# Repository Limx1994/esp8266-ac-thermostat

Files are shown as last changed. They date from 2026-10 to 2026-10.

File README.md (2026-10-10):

# 🌡️ 恒温养人控制器

> **空调负责干活，我负责让它懂事。**

一个基于 **ESP-12F** 的低功耗空调温控器。

它会自己测温、判断冷热、发送已经学会的遥控器指令。
不用 App，不连云端，配置完之后基本不用管。

## 能干什么

- 🌡️ DS18B20 自动测温
- 🎯 两组独立温控规则
- 📡 学习并发送空调红外指令
- 📱 手机连接 Wi-Fi 直接配置
- 💤 闲着就 light sleep，省点电
- 📈 温度变化越快，空调管得越勤

简单来说：

```text
太热了  → 发一个降温指令
太冷了  → 发一个升温指令
挺舒服  → 接着睡
```

## 怎么用

按 **S1** 开启热点，手机连接：

```text
空调智能温控
```

没有自动弹出页面时访问：

```text
http://192.168.4.1
```

设置温度 → 学习遥控器 → 测试发送 → 启用规则。

然后就可以把它扔在一边自己养人了。

## 实物图

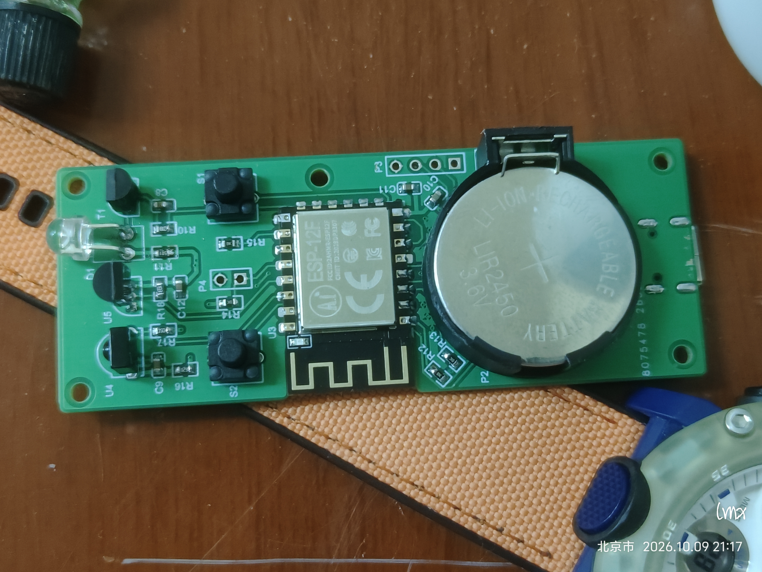
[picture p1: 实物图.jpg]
恒温养人控制器实物


## 配置页面

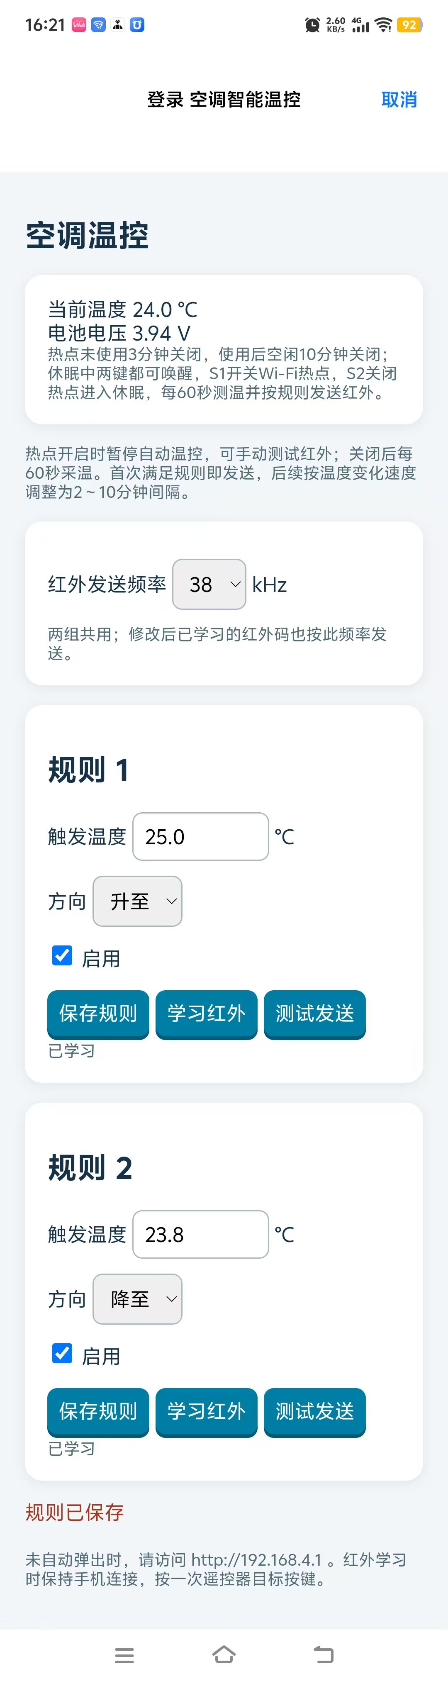
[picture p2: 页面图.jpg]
手机配置页面


## 它什么时候工作

| 状态 | 行为 |
| --- | --- |
| 热点开启 | 每 2 秒测温，方便配置，暂停自动红外 |
| 正常运行 | 每 60 秒测温并检查规则 |
| 空闲期间 | 自动 light sleep |
| 温度变化明显 | 自动发送间隔按趋势调整为 120～600 秒 |

S2 可以快速关闭热点，但**不会停止温控**。

## 构建

```powershell
Set-Location .\Sof
python build.py
python flash.py --port COM3 --dry-run
```

以上命令从本工作区根目录执行；构建和测试在 `Sof` 目录执行，Git 管理根目录为 `D:\空调温度`。默认分段烧录保留未覆盖的 NVS。

如果已经学好了遥控器，别随手整片擦 Flash，不然它会把自己刚学会的东西忘掉。

## 当前状态

本次发布版本（新增修复尚未重新实机验收）：

```text
0.5A · 2026-10-10
```

2026-10-09 用户确认：红外与 1-Wire 波形、空调响应、真实休眠/功耗、温度准确度、手机弹页、ADC 多电压点及 24 小时运行均已完成实机验证。该状态依据用户反馈；本次未补充具体测量数值、设备镜像哈希或测量记录。

0.5A 发布附件包含：

**网页温度/电压校准 / 学习按钮与 LED 反馈 / 分状态电压修正 / 红外与按键诊断**

保留 80 MHz、温度校准、60 秒采温和 120～600 秒趋势自动发送。本次纳入隐藏校准、学习状态反馈、电压单点修正及诊断日志；此前实机确认不直接替代新增修复镜像的验收，详情见 [本地发布](Sof/README.md#本地发布)。

既有文档记录的低电流读数（对应镜像、测量接点与积分条件未确认）：

```text
3.994 V · 10 µA
```

该读数不作为当前构建的功耗验收结果；仅凭 light sleep 配置不能确认整机电流或续航。当前软件检查与用户实机验证确认见 [本地发布](Sof/README.md#本地发布)。

## 文档导航

- [项目说明与软件检查](Sof/README.md)
- [硬件引脚与接线](Sof/ESP-12F硬件引脚与链路说明.md)
- [编译环境](Sof/ESP8266编译环境路径.md) · [烧录工具](Sof/tools/README.md)
- [功耗验收](Sof/README.md#功耗验收) · [温度校准](Sof/README.md#温度测量与校准)

本项目根目录为 `D:\空调温度`：`Sof` 为固件与测试，`Ad` 为硬件设计，`dxf-pdf` 为元件资料与 DXF 文件。

## 下载与许可

- [GitHub 仓库](https://github.com/Limx1994/esp8266-ac-thermostat)
- [0.5A Release](https://github.com/Limx1994/esp8266-ac-thermostat/releases/tag/v0.5A)：分段烧录包、完整镜像及 SHA256 校验清单。保留规则和红外编码时使用分段烧录；完整镜像会清除 NVS。
- 项目采用 [PolyForm Noncommercial 1.0.0](LICENSE)，附带第三方工具保留其原有许可。

---

**目标就一个：**

> 少折腾空调，多养养人。

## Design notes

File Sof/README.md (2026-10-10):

# 🌡️ 恒温养人控制器

> 空调负责干活，我负责让它懂事。

基于 ESP-12F 和 ESP8266 RTOS SDK 3.4 的空调温控器：DS18B20 测温、两组独立规则、红外学习与发送，手机连接本机热点配置；不依赖 App 或云端。热点关闭时每 60 秒采温，自动发送间隔随温度趋势在 120～600 秒调整，空闲时允许 light sleep。

## 文档导航

- [手机配置](#手机配置) · [运行行为](#运行行为) · [软件检查](#软件检查)
- [温度测量与校准](#温度测量与校准) · [电池电压](#电池电压) · [功耗验收](#功耗验收)
- [硬件引脚与接线](ESP-12F硬件引脚与链路说明.md) · [编译环境](ESP8266编译环境路径.md) · [烧录工具](tools/README.md)
- [本地发布与验证状态](#本地发布)

当前发布为 **0.5A（2026-10-10）**，标签 `v0.5A`。相对 0.1K，新增网页校准、学习状态反馈、分状态电压修正及诊断日志；新增校准 API 与 NVS 键，已有规则、红外码和载波数据保持兼容。验证状态见 [本地发布](#本地发布)。

Git 根目录为上层 `D:\空调温度`；本目录 `Sof` 仍是固件构建与测试入口。上层 `Ad` 保存硬件设计，`dxf-pdf` 保存元件资料和 DXF 文件。原有历史保留，迁移前版本的路径以当时树结构为准。

## 手机配置

1. 按 S1 开启热点，连接开放 Wi-Fi `空调智能温控`。未自动弹页时访问 `http://192.168.4.1`。
2. 设置两组规则的触发温度（−10～50 °C）、升温或降温方向，保存规则。
3. 点击对应组的“学习红外”，在 15 秒内按一次遥控器目标按键；学习成功后先用“测试发送”验证，再启用并保存规则。
4. 两组共用红外发送频率（36/38/40 kHz，默认 38 kHz）。修改后保存到 NVS，并影响所有已学习编码的后续发送。HS0038B 不能测出遥控器载波频率，需用目标空调验证兼容性。

学习码写入并提交 NVS 后，会读回逐字节核对；核对失败不显示学习成功，当前内存中的旧编码保留，但已提交的 Flash 内容需重新学习确认。学习成功、开机加载及发送完成日志均记录 `code=` 内容校验值，同一组可据此对比重启或休眠前后是否变化。启动时缺失或无效的 NVS 编码会明确记录。默认 `python flash.py` 分段烧录不覆盖 NVS；整片烧录 `full_flash.bin` 或擦除 Flash 会清除保存的数据。编码仍在但空调无响应时，还需核对学习波形及实际发射。

点击学习后，该组按钮立即显示“学习中···”，等待及采集期间保持；两组学习按钮暂时禁用，成功、超时或其他失败后恢复“学习红外”。页面底部继续保留详细结果；若页面重新打开时已有学习在进行，接口未提供学习槽位，两组按钮均显示“学习中···”并禁用，结束后恢复。

## 温度测量与校准

当前接法按用户确认：外置裸 DS18B20、VDD/DQ/GND 三线供电、DQ 使用 4.7 kΩ 上拉、引线不超过 1 米。相邻显示变化 0.1～0.2 ℃本身不能证明绝对误差超标。目标是在 18～30 ℃内实测误差不超过 ±0.5 ℃，±0.3 ℃仅作为改善目标；[DS18B20 官方数据手册](https://www.analog.com/media/en/technical-documentation/data-sheets/ds18b20.pdf)给出的 −10～85 ℃精度为 ±0.5 ℃，12 位分辨率为 0.0625 ℃。尚无参考温度计对照数据，默认偏移为 0，不加滤波或控制回差。

先固定探头在通风处，避开主板、电源、充电电路、日晒及空调直接出风，避免手持；检查接点与探头端供电，若探头端没有去耦，在 VDD/GND 附近增加 100 nF 电容。参考温度计的已知准确度须优于 ±0.2 ℃，两探头靠近但不接触，保持相同高度和气流，裸传感器不直接浸水。热平衡至少 15 分钟且参考读数稳定后，连续记录 10 分钟配对数据；分别对照热点开启、关闭及 USB 充电状态，记录平均偏差、波动范围和读取失败次数。建议记录列为时间、参考温度、`raw16`、`temperature10`、AP/充电状态和错误；`raw16 / 16` 为未校准摄氏温度。现场安装、去耦、参考仪器及这些测量均尚未核验。

若误差达标，保留零偏移。若偏差随热点或充电状态明显变化，先解决安装受热，不能用固定偏移补偿；只有热平衡后的稳定偏差才做单点校准。在约 25 ℃求 `偏移℃ = 平均参考温度 − 平均原始温度`，四舍五入为 0.1 ℃的整数填入固件目录生成配置 `sdkconfig` 的 `CONFIG_APP_TEMP_OFFSET10`，再执行 `python build.py`。例如参考为 25.0 ℃、原始平均为 25.3 ℃时设为 `-3`，即减 0.3 ℃。范围为 −50～50（±5.0 ℃），不是允许误差；明显大偏差应先排错。`sdkconfig.defaults` 默认值为 0，不覆盖已有 `sdkconfig`，构建后须核对 `build\auto\config\sdkconfig.h` 的实际值。编译偏移不写入 NVS；0.5A 提供网页追加偏移，见 [网页隐藏校准](#网页隐藏校准)。

固件在原始 1/16 ℃读数上应用偏移后，仅做一次四舍五入到 0.1 ℃；显示与规则判断共享同一结果。每次转换前读取并 CRC 校验 scratchpad 的分辨率，只有低于 12 位时才保留 TH/TL 并修正 RAM，读回确认后启动转换，不写传感器 EEPROM。核验/读回失败上报错误并阻止本次控制；结束读取仍保留 CRC/设备未找到最多三次重读、85 ℃默认值拒绝及 GPIO 清理错误上报，转换后分辨率变回低位也拒绝该读数。日志 `raw16`、`resolution=12`、`offset10`、`temperature10` 用于追踪原始与校准结果；这些日志表示有效 scratchpad 已解码，最终成功还要求总线清理成功。静默 UART 配置下不输出运行诊断。

校准后在约 18 ℃、30 ℃独立复核，并在三个温点分别检查热点开启/关闭、充电状态及休眠恢复后的读数与规则触发。仅在参考稳定的区间评估，配对温度误差须不超过 ±0.5 ℃；记录失败数量和原因，不将失败或缺失读数计作成功。若多温点仍不能达标，停止追加补偿，换用可追溯来源的 DS18B20 后重新核验。软件测试不能代替此项实机精度验收。

## 电池电压

电压随测温采集，使用 `adc_read` 单次读取，按当前板实测参考做单点增益校准；返回值超出 0～1023 时报错，不额外开启 RF。页面每 2 秒刷新、显示两位小数，刷新不增加采样频率。日志的 `measured` 仍保留按 330 kΩ / 82 kΩ 名义分压换算的未校准值。

boot 原 ADC 参考为 843；2026-10-10 用户确认外部模拟电池的稳定 3.795 V 为基准，冷启动 ADC746，网页比例为 `3794/3790`。扣除网页比例后将 boot ADC 参考改为 786，基准换算为 `battery_mV = round(adc × 3994 / 786)`，ADC746 基准3791 mV、追加后3795 mV。AP 保留同步样本 `adc=702 → 3595 mV`，换算为 `round(adc × 3595 / 702)`。sleep 原参考为 909.5；同一 3.795 V 基准下连续 11 次非 AP 采样有 10 次 ADC811、1 次 ADC812，网页比例为 `3794/3790`。扣除网页比例后拟合 sleep，将双倍 ADC 参考从 1819 改为 1709，基准换算为 `round(adc × 3994 × 2 / 1709)`；随后仍追加网页比例，ADC811 得到 3795 mV，ADC812 得到 3799 mV。所有分支使用整数运算保留 ADC 变化，取代旧 101/111 临时补偿。AP 关闭且经历允许自动休眠的等待后使用 sleep 参考，其余使用 boot 参考；该状态标记不证明实际已经入睡。

日志保留 `adc`、`measured`、`compensated` 及 `cal=boot/ap/sleep`；`measured` 为原名义换算值，不是万用表实测值。`compensated=1` 只表示选用 sleep 校准分支，所有分支都做校准。页面和低电量判断使用分状态基准再乘网页比例后的电压：低于 3.5 V 提示，达到 3.5 V 隐藏；读取失败显示错误，不影响温控。boot、sleep 基准根据本板稳定 3.795 V 样本修正，AP 保留 3.595 V 样本；其他板、160 MHz 或其他电压点应重新实测。ADC 状态差异根因及全电压范围精度未确认，3.5 V 边界仍需独立核验。

电压诊断另记录 `base_mv`（分状态换算结果）、`ratio=参考mV/基准mV`（网页追加比例）及最终 `battery`，这些数值来自同一次状态锁快照。`phase=ap/cold-start/after-ap` 区分热点采样、未开启过热点的采样和热点关闭后的采样；该阶段与 `cal` 分支分别记录，不能把 `cold-start` 阶段等同于 `cal=boot`。`off_sample` 为当前非 AP 阶段采样序号（含失败），开启热点清零；`off_ms` 从主循环检测热点关闭后起算，到 ADC 采样时刻为止，冷启动和 AP 时为 0。这些字段不证明真实入睡或唤醒原因，不改变采样周期、ADC 调用次数及原换算系数。

2026-10-10 旧 sleep 系数的对照日志：网页比例 `3794/3790`，AP ADC740～741 显示 3.794～3.799 V；非 AP ADC811 的 sleep 基准为 3561 mV，追加后为 3565 mV，用户同步实测为 3.795 V。随后 11 次稳定样本确认持续偏差，按上述方法单独修正 sleep。实机仍须保持电池端电压稳定，核对关闭 AP 后首次及随后至少 3 轮采样，并补充冷启动、第二电压点及 3.5 V 边界。

### 网页隐藏校准

0.5A 支持在同一标题上 3 秒内点击 5 次：规则 1 打开温度校正，规则 2 打开电池电压校正。两个标题独立计数，超时或关闭弹框清零。弹框显示当前读数；输入参考仪表实测值后保存，取消不修改配置。保存期间禁止重复提交；失败保留输入并显示原因，成功关闭并刷新读数。

弹框宽度包含内边距，最大 340 px，内容超出高度时内部滚动；打开时不自动聚焦或弹出键盘。弹出后的前 800 ms 忽略保存、取消，避免五次点击后的惯性点击误提交或立即关闭；之后点击输入框进行编辑并正常保存/取消。

温度参考范围 −10～50 ℃，输入精度 0.1 ℃；追加偏移为 `参考温度 − 未经网页校准的温度`，限制 ±5.0 ℃。保留原编译偏移，网页追加偏移参与页面、温控和 thermostat 日志；sensor 的 `temperature10` 诊断仍表示应用编译偏移后的基准。成功校准清空趋势和规则判断状态，保留成功发送计时，避免校准跳变被当作温度趋势。

电压参考范围 2.5～4.5 V，输入精度 0.001 V；比例为 `参考电压 / 当前 AP 基准电压`，限制 0.5～1.5。boot/AP/sleep 各自按分状态 ADC 系数换算，再统一乘网页比例并整数四舍五入，参与显示、thermostat 日志及低电量判断。网页修改人工目标后，保存的新比例同时用于三个状态，并在重启时加载；boot 不固定输出 3.795 V。非 AP 不使用 AP 的 ADC 参考。两类重复校准均替换追加参数，不累加或累乘。

`POST /api/calibration` 接受温度 `{"type":"temperature","reference10":255}` 或电压 `{"type":"battery","referenceMv":3595}`。服务端使用最近一次有效基准样本，超过 5 秒、读取失败或电压基准为零时拒绝；电压要求 AP 样本。参数或幅度越界返回 400，样本不可用返回 409，存储失败返回 500，成功返回 200。

追加参数分别写入 `ac` NVS 的 `temp_adj` 和 `bat_adj`，提交成功才更新内存及当前读数；存储失败保留原参数。重启加载，缺失使用零偏移和单位比例；损坏或读取失败明确报错并按现有启动错误机制终止。已有规则、红外编码及载波 NVS 格式保持兼容。单点校准不能证明全范围准确，需核对温控判断、相同电池电压下 AP/非 AP/休眠后的读数。

## 运行行为

| 状态 | 测温与控制 | 指示灯 |
| --- | --- | --- |
| 开机、热点关闭 | 开机立即测温，之后每 60 秒测温并检查规则 | 熄灭 |
| 热点开启 | 每 2 秒测温，暂停自动发送与趋势计算 | 每秒亮 500 ms |
| 红外学习 | 等待信号和采集期间保持唤醒，结束后恢复热点指示 | 常亮 |
| S2 休眠温控 | 关闭热点，每 60 秒测温并检查规则，间隔允许自动 light sleep | 熄灭 |

S1 可提前关闭热点；红外学习或发送期间将关闭请求延后到红外空闲，再按 S1 可取消待处理请求。休眠中 S1、S2 均通过 GPIO 唤醒：S1 开关 Wi-Fi 热点，S2 快速关闭热点并返回休眠温控。S2 关闭热点后继续每 60 秒采温和按规则发送红外；重复按 S2 不暂停温控、不清空规则状态，S1 可重新开启热点。红外忙碌时，S2 关闭请求延后到空闲；关闭失败会上报错误，温控继续，但不能保证进入休眠。DS18B20 转换期间的按键需等待约 750 ms 加一个 FreeRTOS tick 后处理；长按只产生一次操作。热点关闭失败会记录错误，保留状态供再次操作。

热点开启后，未访问控制页或操作配置 API 时，3 分钟后关闭；使用后从最后一次上述操作起空闲 10 分钟关闭，自动回到休眠温控。状态轮询、系统探测及后台请求不延长期限；红外忙碌时延后关闭。

热点关闭时，每次有效采温判断启用的规则：升温方向在温度大于等于阈值时满足，降温方向在温度小于等于阈值时满足。首次满足立即发送，不要求跨越阈值，也不使用回差。已发送的组须达到当前动态间隔后，在下一次有效采样发送；两组共用间隔、独立记录成功发送时间。

趋势使用最近五点两两斜率的中位数，另取最近两段同方向变化的较小速度作为快速路径，两者取较大绝对速度。目标间隔对应约 1 ℃变化，限制在 120～600 秒；缩短立即生效，延长每次最多增加 60 秒。初始或重置间隔为 600 秒，速度为零时目标为 600 秒。热点开启、测温失败或采样间隔超过 120 秒重置趋势；不会清空各组成功发送计时。日志 `trend` 记录点数、速度、目标与实际间隔，`automatic send` 记录组号和结果。

S2、正常休眠、规则或编码变更不清空成功发送计时。条件不满足、规则禁用、未学习编码或正在学习时不自动发送；测温失败阻止本次发送，恢复后重新判断。发送失败不更新成功计时，后续有效采样可重试。网页测试发送不受自动间隔限制。60 秒采样可能漏掉短暂越界，也可能使实际发送晚于目标间隔。

## 红外与诊断

GPIO5 接收输入启用内部上拉，初始化时关闭边沿中断；仅安装学习回调后开启双边沿，学习结束、超时或出错时先在临界区关闭硬件中断并清除待处理状态，再移除回调，之后才处理编码和 NVS。回调移除失败会明确记录错误，不显示学习成功，硬件中断仍保持关闭。硬件说明记录 GPIO5 已有 11 kΩ 外部上拉，不能仅凭拆除接收管就认定引脚悬空；非学习期间关闭中断用于避免无用的边沿处理，节电效果待实测。

红外学习按 10 μs 单位保存完整解调时序，最多 960 段、总时长不超过 750 ms。捕获使用 `esp_timer_get_time()` 计时，保存尾部空闲段；超限、无效波形或保存失败均报错，保留旧编码。学习流程及 NVS 格式保持兼容，无需重新学习；AP 开启时使用 I2S WS + FRC1，AP 关闭时使用 GPIO14 软件载波。清理失败会报错并阻止自动休眠。

DS18B20 的复位和逐位读写使用 RTOS 临界区保护。关键时隙函数放在 IRAM，直接读写 GPIO4 寄存器，按构建配置（当前固定 80 MHz）的 CPU 计数器等待各边沿和采样点，避免临界区内的 GPIO API 和 Flash 延时函数带来缓存等待。读位在起始后约 13 μs 采样；计数器差值支持回绕。临界区不覆盖 750 ms 转换等待，也不在其中输出日志；CRC 失败仍报错，不采用旧温度代替有效读数。主机模拟与链接检查不能代替实际 1-Wire 波形和休眠后测温验证。

发送取得忙碌标志和独立休眠锁后，根据 `portal_is_on()` 固定本次路径，日志标记 `backend=i2s/software`。发送前输出编码校验值、恢复 GPIO14 推挽输出并等待 UART 发完；帧内不输出诊断日志。AP 开启路径保留原有 I2S WS + FRC1，不使用 DMA，也不通过 `GPIO_IN` 回读作为发送成功门槛。

AP 开启路径通过 SDK 已链接的 `rom_i2c_readReg_Mask` / `rom_i2c_writeReg_Mask` 保存、使能并读回音频时钟位，仅操作 block `0x67`、host `4`、register `4` 的 bit `7`；定义依据为 [ESP8266 Arduino 的 I2S_CLK_ENABLE](https://github.com/esp8266/Arduino/blob/master/cores/esp8266/esp8266_peri.h)。`audio clock: before=... enabled=...` 记录保存值及使能后读回值；使能验证失败明确报错。停止 I2S 后恢复原值；停止或恢复失败保留原值及休眠锁，后续重试成功再释放。已有未清理的 I2S 状态不能通过软件路径绕过。

AP 关闭路径直接跳过音频时钟读写、I2S 配置和启动，不先尝试使能再回退，也不调用 `phy_open_rf()` 或开启热点。先停止 FRC1、将 GPIO14 拉低，再在整帧 RTOS 临界区内按保存的包络输出软件载波。关键函数及调用链在 IRAM，直接写 GPIO 寄存器，按构建配置（当前固定 80 MHz）的 `ccount` 累计截止时间计时；周期为 `round(cpu_mhz * 1000000 / frequency_hz)`，高电平占约半周期，支持 36/38/40 kHz。末尾不完整载波周期在包络截止时截断。保留现有段长和总长范围，最长 750 ms 内普通 RTOS 中断及按键处理会延后；NMI 看门狗保持启用。

软件发送记录 `late_cycles`，为边沿或包络结束相对截止时间的最大迟到 CPU 周期数；当前 80 周期为 1 μs。超过 400 周期（5 μs）时立即拉低输出并返回 `ESP_ERR_TIMEOUT`，不计入成功发送间隔，后续有效采样可重试。5 μs 是软件故障检测阈值，不代表实测精度。发送结束或失败均退出临界区、拉低输出并停止 FRC1；只有整帧完成且清理成功才返回 `ESP_OK`。FRC1 ISR 在软件路径不操作包络或 GPIO mux。

历史实机日志将 AP 关闭后的失败定位到 `stage=clock-enable`：音频时钟置位后读回仍为 0，实际包络为 `segments=0/140`。底层时钟为何不能恢复尚未确认；软件路径绕过该阻断，用户已于 2026-10-06 确认此前 160 MHz 软件载波实机验收成功；已有 80 MHz 基线的 AP/休眠红外正常反馈，最新实机验证确认见 [本地发布](#本地发布)。两条路径均保留 `esp_sleep_lock()` / `esp_sleep_unlock()` 独立保护，清理失败保留锁，后续清理成功释放，避免重复加锁；两条路径均不因发送改变 RF 状态，自动成功发送按每组 120～600 秒动态间隔计时。

最近一次发送的返回值、路径、阶段、包络完成段数、最大迟到周期数及 I2S 时钟状态留在 RAM，下次采样前通过 `previous send` / `previous clock` 输出。`seq` 为发送序号；多次发送只保留最近一次，断电或复位不保留。软件路径输出 `previous clock: not used`，时钟字段内部为 `-1`，不冒充使能或恢复成功。`stage=envelope result=ESP_ERR_TIMEOUT` 在软件路径表示时序迟到，在 I2S 路径表示等待包络完成超时；清理错误另列。`carrier configured` 和 `software carrier configured` 中的 `calculated` 均为配置计算频率，不是实测频率。`send complete` 或 `ESP_OK segments=140/140` 只代表发送流程及清理完成，不能证明空调已接收。

主机测试分别以 80/160 MHz 编译，覆盖启动频率不匹配、实际源码的 GPIO 边沿、三种载波配置、整帧包络、750 ms 边界、计数器回绕、模拟 NMI 延迟、清理失败重试、NVS 编码保存及两组动态间隔；模拟结果和链接检查不能证明硬件输出准确。实机验收以空调实际响应为准，用户已确认此前 160 MHz 软件载波验收成功；80 MHz 基线也已收到 AP/休眠红外正常反馈；用户已确认当前红外波形和空调响应通过实机验证；所有遥控协议及三种载波配置的完整兼容性未逐项声明。

## 休眠与供电

正常测温间隔和 S2 休眠温控使用 SDK 自动 light sleep，定时唤醒采温及发送红外，完成后继续休眠。热点关闭期间通过 SDK 的 `phy_close_rf()` 关闭 RF，包括测温和红外处理时；开启热点前通过 `phy_open_rf()` 恢复 RF。热点开启、1-Wire 通信、红外学习或发送期间保持 CPU 唤醒。每次测温先检测 DS18B20 供电：独立供电、热点关闭且红外空闲时，GPIO4 切为输入，由板上 4.7 kΩ 上拉维持 DQ 高电平，转换等待允许休眠；读取前关闭自动休眠并恢复开漏输出。RF 开关流程已纳入主机测试，用户已确认真实休眠/功耗完成实机验证；具体电流及 RF 测量记录未在本次补充。

转换等待保持 750 ms，并额外等待一个 tick 防止提前读取；转换前核验并确保 12 位分辨率。寄生供电时输出一次警告，保持唤醒等待，不提供强上拉支持。主任务等待下一次采样期限，按键通知可提前唤醒；单次上限按 CPU 频率保留 32 位计时余量，80 MHz 下单次最多约 52.68 秒，160 MHz 回退时最多约 25.84 秒；60 秒采温等待会分段，分段不额外采温。实际睡眠时长仍由 SDK 调度器决定。休眠配置失败后尝试关闭自动休眠并继续温控；若已启用的休眠无法关闭，则中止运行并报错。

本项目使用 LIR2450 锂电池，容量约 120 mAh。电池端功耗测量、按键和连续运行验收见 [功耗验收](#功耗验收)。当前节电比例与续航尚未确认。

休眠诊断使用现有链接包装机制，在 RAM 中累加，随测温采样、间隔至少 30 秒输出两行 `sleep_trace`；不增加任务、定时器、RTC 校准或休眠锁。`auto` 是 SDK 自动入口次数，`auto_no_hw` 是入口返回前没有低层尝试的次数；`hw` 是低层尝试，`hw_ok` 仅表示原函数返回 0，`hw_reject` 是硬件报告拒绝的次数。这些次数及 `bad_cal`、`zero_rtc` 均为本窗口增量；窗口可能跨越未完成的入口，不能要求计数严格相加。

`rtc_call_est_ms` 是本窗口未报告拒绝的低层调用前后 RTC 区间估算，使用本次 SDK 校准值，包含进入/退出开销，不使用尚未补偿的系统时间计量睡眠。`bad_cal` 和 `zero_rtc` 分别表示因缺少有效校准或 RTC 未推进而跳过估算的次数；`max_est_ms_total` 为启动以来单次最大估算值，`last_reject` 为最近一次非零返回值。`reasons=unavailable` 表示不能区分 SDK 内部锁、模式、GPIO 和期限等提前退出原因。统计及其与 `window_ms` 的比值不能作为精确睡眠时长或占比；诊断日志本身也有耗电，电流对比须保持相同诊断配置。操作步骤见 [休眠统计验收](#休眠统计验收)。

当前构建开关定义在 `main\Kconfig.projbuild`，默认值在 `sdkconfig.defaults`；已有 `sdkconfig` 不会自动同步。改变开关后须重新构建并核对生成配置。

| 配置 | 当前默认值 | 行为与限制 |
| --- | --- | --- |
| `CONFIG_APP_PAUSE_NOISE_TIMER` | 开启 | RF 关闭后取消 SDK 噪声定时器并阻止重登记，AP 启动前恢复；仅实际软件定时器队列为空时忽略旧 FRC2 alarm，保留计数及唤醒时钟补偿 |
| `CONFIG_APP_PAUSE_NETWORK_TIMERS` | 开启 | AP 关闭后在 TCP/IP 线程同步暂停周期及按需 TCP 定时器，开启前恢复；保留一次性超时，暂停期间网络状态不按周期老化 |
| `CONFIG_APP_DISABLE_DHCP_CLIENT_TIMERS` | 开启 | 构建时移除 DHCP 客户端 fine/coarse 周期项，保留 DHCP 服务端；仅适用于当前 AP 用途，增加 STA 前须关闭并重验 |
| `CONFIG_APP_QUIET_UART` | 关闭 | 开启时初始化后关闭运行日志并将 GPIO1 切为输入；排错需关闭并重新构建 |
| `CONFIG_APP_IDLE_BOOT_PINS` | 开启 | 初始化后释放 GPIO0/15 为无内部上下拉输入，依赖板上外部启动电阻 |
| `CONFIG_APP_SENSOR_IDLE_INPUT` | 开启 | GPIO4 初始化、转换启动失败或读温完成后释放为输入，下一次事务恢复开漏 |
| `CONFIG_APP_TEMP_OFFSET10` | 0 | 在原始温度舍入前应用 0.1 ℃整数偏移，未取得稳定偏差时保持 0 |

定时器恢复/停止失败明确返回错误；网络停止失败时不暂停其定时器。诊断随原采样汇总，不新建任务或周期定时器：最近最多 4 次低层调用记录 RTOS/FRC2 期限与 RTC 区间，`frc2_pending` 表示实际 SDK 软件定时器队列是否非空；最多 16 个 `wait_task` 组合只记录大于 0 且不超过 1 秒的请求等待，零等待、长/无限等待及溢出分别计入 `filtered_zero`、`filtered_long_or_infinite`、`dropped_full`。这些记录不是实际超时或真实唤醒原因，调用地址必须用同一镜像 ELF 解码。`noise_timer` 与 `network timers paused/resumed` 日志用于检查暂停、恢复和剩余队列，具体步骤见 [功耗验收](#功耗验收)。

## 构建与烧录

在 `Sof` 固件目录使用 PowerShell；从项目根目录先执行 `Set-Location .\Sof`：

```powershell
python build.py
python flash.py --port COM3 --dry-run
```

构建脚本扫描 `main` 的 C 源文件并更新组件源文件列表，临时映射空闲的 `Z:`，使用 CMake 和 Ninja `-j 12`，产物位于 `build\auto\`。SDK 可通过 `IDF_PATH` 覆盖，工具路径见 [编译环境说明](ESP8266编译环境路径.md)。从其他目录运行时使用脚本的绝对路径。

`sdkconfig.defaults` 设置 CPU 固定 80 MHz、晶振与 Flash 各 26 MHz、`CONFIG_PM_ENABLE=y`、HTTP 请求头上限 2048 字节和 URI 上限 1024 字节。已有 `sdkconfig` 不会被 defaults 覆盖，须同步选择 80 MHz；实际参数以构建生成的 `sdkconfig.h` 和 `flasher_args.json` 为准。

项目 `components\esp_http_server` 覆盖 SDK 的路由、解析和 socket 错误处理，其余实现、头文件及 Kconfig 继续使用指定 SDK。末尾 `*` 匹配剩余路径，`/generate_204_*` 探测重定向至控制页，`/mmtls/*` 的 GET/POST 返回 404。不支持的协议起始字节直接关闭连接，以 INFO 记录原因；HTTP 解析失败返回错误并关闭连接，收发错误保留真实 `errno`。

dry-run 只检查布局，不打开串口、不写 Flash。实际接线与烧录命令见 [工具说明](tools/README.md)；分段偏移以本次构建为准。完整 4 MB 镜像的未使用区域填 `0xFF`，整片写入会清除 NVS；保留规则和编码时使用分段烧录。

## 软件检查

以下命令逐条执行，成功后再执行下一条：

```powershell
New-Item -ItemType Directory -Force build_ascii | Out-Null
& "D:\APPS\Espressif\tools\ninja\1.9.0\ninja.exe" -f tests\build.ninja -j 12
.\build_ascii\rules_test.exe
python tests\test_power.py
python tests\test_portal.py
python -m unittest discover -s tests -p test_flash_port.py
python -m unittest discover -s tests -p test_tools.py
node --check tests\check_page.js
node tests\check_page.js
python flash.py --port COM3 --dry-run
git diff --check
```

规则测试检查阈值、等号、首次满足、重复满足及禁用规则；功耗主机测试检查实际控制、传感器和红外代码的流程与错误处理；HTTP 主机测试检查路由、解析、请求体清理、超时与 socket 错误；串口测试检查自动选择条件；页面检查验证六个 API 路径、2 秒刷新、共享载波保存、隐藏校准及温度/电池错误显示。

主机测试使用现有 GCC 和 SDK mocks，C 编译启用 `-Wall -Wextra -Werror`，产物保存在 `build_ascii\`。功耗测试需要本次构建生成的 SDK 副本，须先运行 `python build.py`。测试覆盖 80/160 MHz、基线/测量配置及温度偏移，另检查实际 SDK 定时器表、暂停/恢复与失败回退。这些测试不验证实际睡眠、电流、红外波形或手机弹页；最新结果与硬件待验项见 [本地发布](#本地发布)。

### 覆盖统计

以下运行器及扩展测试纳入 0.1J 源码，0.1I 发布不包含它们。先执行 `python build.py`，再从 `Sof` 目录运行以下命令。coverage 已安装在项目内忽略目录时可跳过安装命令，不增加固件依赖：

```powershell
python -m pip install --target build\coverage\packages coverage==7.16.2
python tests\run_coverage.py *> build\coverage\run.log
```

运行器使用 GCC/gcov、Python coverage 和 Node.js V8，复用现有主机测试；每个 C 编译组合保存独立计数。报告位于 `build\coverage\report.md`，关键路径矩阵、未命中源码行/分支、原始统计和产物哈希保存在同目录。C 行/函数按源码位置合并，分支按各变体分别计数；另提供相同 gcov 图结构的汇总，原始分母和缺口保留，不代替逐配置验收。V8 块范围不能等同于 GCC 分支。未插桩源码明确列出，测试、第三方 SDK 和附带工具不纳入业务覆盖率。

0.1J 的 HTTP 修复包括拒绝非 HTTP/1.x、零字节发送报错、接收缓存截断复制和 URI 分配失败槽位清理；相关覆盖统计适用于本次验证源码，不代表 0.1I 发布镜像。

所有可执行检查通过仍不代表全覆盖：存在覆盖缺口时运行器返回 `1`，报告标记“未完成”。代码中的保护分支不自动豁免；当前主机结果不证明实机波形、功耗、精度或真实并发。烧录动作由 mock 或 dry-run 验证，不写入设备。

## 清理

在 Windows PowerShell 5.1 中执行 `.\clean.ps1` 直接清理，使用 `.\clean.ps1 -WhatIf` 预览、不删除文件。原有 `-Apply` 参数保持兼容，显式传入 `-Apply:$false` 也可仅预览。脚本可通过绝对路径从其他目录调用。

清理范围为 `build\s1_checkpoint`、`build\s1_build.log`、整个 `build_ascii`、根目录 Ninja 状态、根目录 `__pycache__` 及 `main`、`components`、`tests` 中的 Python 缓存。保留 `build\auto`、其他检查点、`sdkconfig`、源码、测试、文档、CSV、工具和 `.git`。目标含 Git 跟踪文件或重解析点时停止；输出删除、跳过及失败统计。清理后需先重建 `build_ascii` 再运行规则测试。

## 串口与验证状态

使用 3.3 V USB-UART 接 P3-2（TXD）和 P3-4（GND），以 115200 baud 接收 UART0 固件日志。ROM 早期启动为 74880 baud，开头可能乱码。当前关闭 `CONFIG_APP_QUIET_UART`，以 INFO 输出启动、规则、红外、热点、S2 休眠温控请求，以及每次采样开始、成功采集的温度和电池电压；读取失败输出对应错误。日志配置下休眠期间无串口输出，定时唤醒采样后恢复输出。温度保留一位小数，电压以 V 输出、保留三位小数，并记录 SDK 返回的单次 ADC 计数；热点开启约每 2 秒输出，关闭约每 60 秒输出，无需开启 DEBUG。

历史用户日志和反馈确认此前 160 MHz 构建的 Android 自动弹页、红外学习保存及 AP 开启时空调响应；2026-10-06 用户补充确认软件载波实机验收成功。当前 80 MHz 构建的用户实机反馈及未完成验收项见下方。

## 功耗验收

使用同一块板、相同电池电压、规则、编码、接线和日志配置对比镜像；记录 SHA256、CPU 频率、配置及采样周期。软件检查与休眠日志不能证明真实低电流平台或续航。

1. 断开 USB-C 和可能反向供电的 USB-UART，在电池与整机之间测电流；电源和仪表须支持热点、红外发送瞬态，避免接线压降导致复位。
2. 分别记录热点关闭监测、S2 休眠温控、热点开启未连接和单手机使用页面的电流波形及至少 10 分钟平均电流；未使用热点在 3 分钟关闭，须同时记录关闭时刻和整体平均值。
3. 对同一红外编码记录峰值与单次积分电量。分别测模块 VCC 支路和电池端，不能将整板 3.3 V 输出当作模块电流，也不能以最低瞬时值代替平均电流。
4. 仅在降幅超过测量波动时确认改善。电池为约 120 mAh 的 LIR2450，`续航小时 ≈ 实际可用容量 mAh / 电池端平均电流 mA`；可用容量与续航需实测。

### 休眠统计验收

- 保存至少三个完整 AP 关闭窗口，启动、按键、红外发送与 AP 混合窗口单独标注；用同一镜像 ELF 解码调用地址。
- `auto` 是入口次数，`hw` 是低层尝试，`hw_ok` 仅表示返回 0；`rtc_call_est_ms` 包含进出开销，不是精确睡眠时间或占比。保留拒绝、无校准、RTC 未推进和等待记录溢出的数量与原因。
- 比较 RTOS/FRC2 期限和 RTC 区间；真实软件定时器存在时不得强行忽略期限。60 秒采样允许分段等待，不以一次睡满 60 秒为验收标准。
- 若需对比噪声、网络、DHCP 客户端定时器开关，逐项改变并重新构建，保持其他条件一致。至少开关热点 20 次，检查恢复日志、手机获取 IP、HTTP、学习和两条发送路径。
- GPIO 空闲输入和静默 UART 对比也逐项进行；静默版通过页面检查功能，异常改用日志版排查。验证 GPIO0/15 外部启动电阻、冷启动和下载模式，以及 GPIO4 下一次事务恢复。

### 实机功能验收

- 测温与规则：开机立即测温、AP 关闭 60 秒/开启 2 秒；等号、首次满足、两组独立计时、稳定温度及连续快速变化；AP 开启暂停自动发送，关闭后恢复。测试测温失败、发送失败和恢复，不能将失败计为成功。
- 按键与热点：S1/S2 唤醒、短按/长按、转换等待约 750 ms 加一个 tick、红外忙碌延后关闭；热点未使用 3 分钟/使用后空闲 10 分钟关闭，状态轮询不续期；反复开启后手机能重新获取 IP。
- 红外与持久化：两组学习、15 秒超时、保存失败提示、断电保持；同一码验证 AP 开启 I2S 发送、关闭后软件发送及多轮休眠后发送，以空调实际响应为准；按目标设备验证 36/38/40 kHz。
- 温度与电压：按校准章节对照 18/25/30 ℃，核对 CRC、分辨率及清理失败提示；用万用表核对 boot/ap/sleep、第二电压点与 3.5 V 提示边界。允许休眠标记不等于实际入睡。
- 稳定性：连续运行至少 24 小时，记录采样周期、计时漂移、复位、异常和漏发/重复发送；报告失败与跳过数量及原因。

## 本地发布

### 0.5A · 2026-10-10

相对 0.1K，纳入此前本地功能与回归测试：

- 网页隐藏温度/电压校准、弹框宽度及 800 ms 防误触；新增 `POST /api/calibration` 和 NVS `temp_adj`、`bat_adj`，已有规则、红外码和载波数据保持兼容。
- 学习按钮等待/采集反馈、重复启动保护及过期状态响应丢弃；学习期间现有 LED 任务常亮，结束或失败后恢复热点指示。
- 根据本板同步样本修正 boot/AP/sleep 电压基准，三个状态统一追加网页比例；重复校准替换参数，重启加载。
- 增加红外学习阶段、GPIO 接收快照、按键等待和分状态电压日志；不改变 60 秒/2 秒采样及 120～600 秒自动发送间隔。

本轮 6 份 Markdown lint、页面语法和固件 Ninja `-j 12` 构建通过；19 项 Python 单测及 9 组功能/冒烟检查通过，失败 0、跳过 0。包含功耗 28 组合与 SDK 定时器、热点/HTTP、规则、启动、页面、工具、烧录 dry-run、实际配置及 BIN/HEX。18 处外部链接去重为 17 个：14 个返回 HTTP 200，2 个 GitHub 源文件链接返回 HTTP 503，无法确认可访问性；新 Release 链接待发布后核验。

覆盖验收未完成：8 个模块存在缺口，运行器返回 `1`；已插桩 C 行 2512/2515、函数 167/167、逐变体分支机会 6802/7762，Python 工具行/分支全部命中，页面 V8 函数 12/12、块范围 121/121。不同统计口径不可互换。本轮报告输出 `build\coverage\report.txt` 与 `path_matrix.txt`，未新增 Markdown；日志为 `build\release_0_5A_build.log`、`build\release_0_5A_tests.log`。未连接设备、烧录或重新进行实机验收。版本文件和标签为 `v0.5A`，旧标签与附件保留；发布附件按对应提交重新构建，不复用版本字符串仍为 `v0.1K` 的诊断包。

学习日志 `stage` 区分任务创建、回调安装/边沿配置/移除、等待信号、采集、校验及 NVS open/set/commit/readback；`learn RX` 记录 GPIO5 电平、中断、待处理状态、回调次数和段数。ISR 不输出日志。

`button_trace` 记录 `conversion-enter/done`、`wait-enter/done`、`button-dispatch`、`button-action-done` 和 `release-enter/done`，用于区分转换等待、主任务等待、按键处理及释放确认；包含 tick、通知数量、休眠配置、红外忙碌状态和 GPIO12/13 快照。等待前排空 UART，日志会增加唤醒开销，不用于精确功耗验收；这些字段不证明硬件唤醒原因。

故障复现时保留完整启动日志、镜像 SHA256、最后一条 `stage` 及按键时间。仅有 `release-enter` 时核对按键持续低电平；等待入口后无完成记录时保留后续至少两分钟日志。“两键无效且采温停止”尚未实机复现，不能宣称已修复。实际学习、20 轮休眠按键、校准精度与电压范围仍待实机验收。

[0.5A Release](https://github.com/Limx1994/esp8266-ac-thermostat/releases/tag/v0.5A) 提供分段包、完整 BIN/HEX 和 SHA256。分段烧录保留未覆盖的 NVS；完整镜像清除规则、红外码、载波及网页校准参数。

### 0.1K · 2026-10-10

纳入红外发送脚初始化错误检查、热点按键关闭失败重试、扩展回归测试、PCB 工程与 BOM PDF/XLSX。`version.txt` 为 `v0.1K`，发布附件按新标签构建；原有 `v0.1J` 标签与附件保持不变。

本次文档 lint（6 份 Markdown）、页面语法、Ninja `-j 12` 构建、19 项 Python 单测及 9 组功能检查通过，失败 0、跳过 0。包含功耗 28 组合、SDK 定时器、规则、启动、热点/HTTP、页面、烧录 dry-run、实际配置与 BIN/HEX 一致性检查。17 个外部文档链接未在线核验。

覆盖验收未完成：8 个模块有分支缺口，运行器返回 `1`；已插桩 C 行 2322/2322、函数 159/159、逐变体分支机会 6184/7050。Python 工具行/分支全部命中，V8 函数 7/7、块范围 44/44；不同统计口径不可互换。此前用户确认的实机验证保留；新增修复镜像未重新进行实机验收。

[0.1K Release](https://github.com/Limx1994/esp8266-ac-thermostat/releases/tag/v0.1K) 提供分段烧录包、完整 BIN/HEX 和 SHA256 清单。分段烧录保留未覆盖的 NVS；完整镜像会清除规则、红外编码及载波设置。

以下为历史发布记录，不代表 0.5A 的验证结果。

### 0.1J · 2026-10-09

纳入 HTTP 与热点清理修复，以及规则、启动、功耗、热点/HTTP、串口、构建/烧录工具和页面扩展回归测试。`version.txt` 为 `v0.1J`；标签创建后构建对应发布镜像。

文档 lint（6 份 Markdown）、页面语法检查、固件构建（Ninja `-j 12`）、19 项 Python 单测及 9 组功能检查全部通过，失败 0、跳过 0。检查覆盖规则、启动、功耗 24 组合与 SDK 定时器、热点/HTTP、页面、烧录 dry-run、实际配置及 BIN/HEX。16 个外部链接未在线核验。

覆盖验收仍未完成：10 个模块存在分支缺口，运行器返回 `1`。已插桩 C 行 2321/2321、函数 159/159，按编译变体统计的分支机会 4528/5906；Python 三个工具行与分支全部命中，页面 V8 函数 7/7、块范围 44/44（不同统计口径不能互换）。2026-10-09 用户确认：红外与 1-Wire 波形、空调响应、真实休眠/功耗、温度准确度、手机弹页、ADC 多电压点及 24 小时运行均已完成实机验证。该状态依据用户反馈；本次未补充具体测量数值、设备镜像哈希或测量记录。

[0.1J Release](https://github.com/Limx1994/esp8266-ac-thermostat/releases/tag/v0.1J) 提供分段烧录包、完整 BIN/HEX 和 SHA256 清单。分段烧录保留未覆盖的 NVS；完整镜像会清除规则、红外编码与共享载波设置。

后续修复已纳入 0.1K；`v0.1J` 标签与附件保留。

### 0.1K 发布前的本地复验

当时保存的红外初始化检查、热点关闭失败重试及扩展测试已纳入后续 0.1K；旧日志与覆盖数据仅标识当时源码，不代表 0.5A。历史记录可通过 Git 查询。

### 历史发布与验证记录

- **0.1I · 2026-10-07：**Git 管理范围迁移至项目根目录，保留原历史，纳入硬件、参考资料及已验证源码。更新 `clean.ps1` 的工作树检查，并用 `version.txt` 明确发布版本；固件目录、HTTP API 和 NVS 格式保持兼容。[0.1I Release](https://github.com/Limx1994/esp8266-ac-thermostat/releases/tag/v0.1I) 保留对应固件附件和 SHA256 清单。
- **0.1J 发布前的文档复验：**当时工作区包含未提交的 HTTP、热点和测试改动；软件检查通过但分支覆盖验收未完成。这些结果及本地重建哈希不能用于证明 0.1I 发布附件或单独文档提交的固件行为。
- 历史详细记录可从 Git 查询，例如 `git show 5a58cb2:Sof/README.md`；迁移前路径按对应提交树结构查询。当前 `build\auto\` 会被重建覆盖，附件校验以对应 Release 的 SHA256 清单为准。

### 已有实机依据

以下来自历史文档和用户反馈，未重新连接设备，设备镜像 SHA256 未独立核对：

| 阶段 | 已有记录 | 验证边界 |
| --- | --- | --- |
| 0.1H / 160 MHz | 2026-10-06 用户确认软件载波可控制空调，历史记录包含 Android 弹页、学习保存和 AP 下响应 | 不证明当前 80 MHz 趋势组合或所有协议已验收 |
| 80 MHz 基线 | AP/休眠红外正常反馈；boot/ap/sleep ADC 单点参考为 843/839.5/909.5，对应 3.994 V | 旧采样和发送周期，不能用于当前间隔验收；电压全范围待验 |
| 定时器调整 | DHCP 客户端周期移除和网络周期暂停后，历史等待统计发生变化 | 日志次数不等于积分电流；最新组合的热点恢复仍待验 |
| 历史功耗 | 2026-10-06 记录 light sleep 5.125 mA、临时 deep sleep 4.613 mA，均为 3.994 V | 仪表、测量接点和积分方式未提供；正常固件仍使用 light sleep |
| 入口文档的低电流记录 | 曾记录 3.994 V / 10 µA | 缺少对应镜像、日志和测量条件，不作为当前构建的功耗验收结果 |

0.1H 的完整发布记录见 `git show 427581a:README.md`，后续历史保存见 `git show 5407fec:README.md`。历史产物哈希只能标识对应镜像；`build\auto\` 会被重建覆盖，不能直接认定设备运行该产物。

### 实机待验

2026-10-09 用户确认：红外与 1-Wire 波形、空调响应、真实休眠/功耗、温度准确度、手机弹页、ADC 多电压点及 24 小时运行均已完成实机验证。该状态依据用户反馈；本次未补充具体测量数值、设备镜像哈希或测量记录。

以下项目不包含在本次用户明确确认范围内：趋势发送、S1/S2 长等待唤醒、热点恢复与手机获取 IP、学习/NVS 断电保持及所有载波/协议兼容性未逐项确认。

GPIO2 实际 LED 接线及 HS0038B 常供电消耗未在本次反馈中逐项确认；GPIO16 未接 RST，不采用 deep sleep。节电比例、精确睡眠占比和续航未提供具体数值。

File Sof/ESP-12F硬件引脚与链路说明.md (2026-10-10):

# ESP-12F 硬件引脚速查

供固件开发与接线核对使用；运行、校准及验收统一见 [项目说明](README.md)。引脚号为原理图中 U3 的物理脚号；代码中使用 GPIO 编号。D1（LED1）已确认为红外发射 LED。

| U3 脚 | 信号 | 硬件连接与软件用途 |
| --- | --- | --- |
| 1 | RST | 10 kΩ 上拉至 3.3 V；低电平复位 |
| 2 | ADC | 通过 330 kΩ / 82 kΩ 分压读取电池 B+ |
| 3 | EN | 10 kΩ 上拉至 3.3 V；高电平使能 |
| 4 | GPIO16 | 未连接 |
| 5 | **GPIO14** | 红外发射：经 R10、T1 驱动 D1；输出高电平时 D1 发光 |
| 6 | **GPIO12** | 按键 S1；按下接地，配置内部上拉，低电平表示按下 |
| 7 | **GPIO13** | 按键 S2；按下接地，配置内部上拉，低电平表示按下 |
| 8、9 | VCC、GND | 3.3 V 供电、地 |
| 10 | GPIO15 | 10 kΩ 下拉；启动时保持低电平 |
| 11 | GPIO2 | 固件用作低电平点亮的状态 LED；启动时需为高电平，芯片有弱上拉；板上实际连接仍需核验 |
| 12 | GPIO0 | 10 kΩ 上拉，同时接 P4-1；启动时拉低进入 UART 下载模式 |
| 13 | **GPIO4** | DS18B20 的 DQ；已有 4.7 kΩ 上拉，使用 1-Wire |
| 14 | **GPIO5** | HS0038B 的 OUT；红外接收信号，已有 11 kΩ 上拉 |
| 15 | **GPIO3 / RXD** | 接 P3-3；原理图写成 `RTX`，实际是 UART0 RXD |
| 16 | **GPIO1 / TXD** | 接 P3-2；UART0 TXD |

## 开发注意

- **电池电压：**`VBAT ≈ VADC × (330 + 82) / 82 ≈ VADC × 5.024`。4.2 V 电池在 ADC 脚约为 0.836 V；固件使用 TOUT 模式、`adc_read` 单次读取，按 `1/1023 V` 与分压比例换算，返回值超出 0～1023 时报错。测电压不额外开启 RF。0.5A 的 boot/sleep 使用 3994 mV 标尺，ADC 参考分别为 786、854.5（sleep 双倍参考 1709），依据稳定 3795 mV 样本扣除网页比例拟合；AP 使用 `adc=702 → 3595 mV`，已替代旧 AP 系数及 101/111 补偿。日志保留 ADC、名义换算值、补偿标记及 `cal=boot/ap/sleep`；页面及 3.5 V 判断使用分状态基准追加网页比例后的校准值。状态标记不证明实际入睡，历史多电压点验证不能证明此次新 AP 系数的全范围精度，仍需独立复验；详见 [电池电压](README.md#电池电压)。
- **串口 P3：**1＝3.3 V，2＝UART0 TXD，3＝UART0 RXD，4＝GND；使用 3.3 V USB-UART。查看日志需连接 P3-2 与 P3-4；烧录还需将 USB-UART TX 接 P3-3。UART0 固件日志为 115200 baud，ESP8266 ROM 的早期启动输出仍为 74880 baud。USB-C 只用于供电和充电，没有 USB 数据连接。项目脚本烧录默认 460800 baud，与日志速率独立；烧录及实机验收状态见 [本地发布](README.md#本地发布)。
- **烧录 P4：**1＝GPIO0，2＝GND。短接 P4 后重新上电或复位，进入 UART 下载模式；正常启动时 GPIO0 为高、GPIO2 为高、GPIO15 为低。
- **电源：**本项目使用 LIR2450 锂电池，容量约 120 mAh。USB-C 5 V 经 TP4057 为电池充电；按当前随附原理图和 BOM，电池经 U2（MG6228T5-33）提供 3.3 V。充电状态脚未接 ESP，固件不能直接读取充电状态。
- **DS18B20：**CPU 当前固定 80 MHz，1-Wire 按配置换算周期，保持原微秒时序；已有 80 MHz 测温日志，用户已确认温度准确度及 1-Wire 波形完成实机验证，具体校准数值未补充。转换前检测供电、CRC 核验分辨率；低于 12 位时修正 RAM 并读回，不写 EEPROM。独立供电时 DQ 可在转换等待期间切为输入，由外部上拉维持高电平；读取前恢复开漏。寄生供电只回退到唤醒等待，不提供强上拉支持，不能据此认定寄生供电可正常测温。
- **红外输出：**GPIO14 接线不变。AP 开启使用 I2S WS + FRC1；AP 关闭使用按当前 80 MHz CPU 计时的 IRAM 软件载波，不恢复 RF 或开启热点。HS0038B 接收的是解调包络，不能识别原遥控器载波频率；36/38/40 kHz 兼容性需用目标空调验证。
- **状态 LED：**GPIO2 低电平点亮，热点开启时每秒亮 500 ms；红外学习等待和采集期间常亮，结束或失败后恢复热点指示，热点关闭时熄灭。GPIO2 的原“未连接”条目与补充 LED 条目存在冲突，此处仅确认代码用途，实际接线和点亮效果需实机核验。
- **休眠：**GPIO12/13 低电平唤醒用于 light sleep；GPIO16 未接 RST，本版本不采用 deep sleep。热点关闭及 S2 休眠温控每 60 秒采温，热点开启每 2 秒；AP 开启暂停自动发送与趋势计算，关闭后自动红外按趋势调整 120～600 秒间隔，两组独立计时，按下一次有效采样执行。电流和续航验收见 [功耗验收](README.md#功耗验收)。

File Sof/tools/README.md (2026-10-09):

# ESP8266 烧录工具

项目脚本使用 `esptool-v4.12.0\esptool.exe`，即已有的 Windows x64 esptool 4.12.0，支持 ESP8266。来源记录：[上游发布页](https://github.com/espressif/esptool/releases/tag/v4.12.0)。已有本地核验记录的版本输出为 4.12.0，SHA256 为：`1cd8386a7934862eb6ce1e14af3cc2309b0a743de1171fd09fab2f2ef2f5d1a3`。同目录保留 [上游说明的中文整理](esptool-v4.12.0/README.md) 和原始 `LICENSE`；可用 `Get-FileHash -Algorithm SHA256 .\tools\esptool-v4.12.0\esptool.exe` 核对。该记录未重新下载或在线比对上游二进制；当前本地文件可按上述命令重新核验。

## 推荐烧录流程

先运行 `python build.py` 生成固件。用 3.3 V USB-UART 将 TX 接 P3-3（RXD）、RX 接 P3-2（TXD），并共接 P3-4（GND）；短接 P4 后复位，使 ESP8266 进入下载模式。在 `Sof` 固件目录的 PowerShell 中运行 `python flash.py --port COM3`，将 `COM3` 改为实际端口。脚本从 `build\auto\flasher_args.json` 读取 Flash 参数和分段偏移，检查文件后调用本目录的 esptool；默认分段烧录，保留未覆盖的 NVS。可先运行 `python flash.py --port COM3 --dry-run` 只检查布局，不访问串口。运行时会输出配置文件、每段地址及 sector、准备执行的命令和烧录结果；`python flash.py --help` 显示完整用法。若需手动烧录，使用以下等效命令：

```powershell
& .\tools\esptool-v4.12.0\esptool.exe --chip esp8266 --port COM3 --baud 460800 `
  --before no_reset --after no_reset write_flash `
  --flash_mode dio --flash_size 4MB --flash_freq 26m `
  0x0 .\build\auto\bootloader\bootloader.bin `
  0x8000 .\build\auto\partition_table\partition-table.bin `
  0x10000 .\build\auto\ac_thermostat.bin
```

不传 `--port` 时可运行 `python flash.py`：脚本会读取系统串口列表，仅在恰有两个串口且其中一个是 COM1 时选择另一个。其他情况会报错，请使用 `--port COMx` 明确指定。`python flash.py --dry-run` 也会自动选择串口，但不会打开串口或写入 Flash。

默认烧录波特率为 `460800`，esptool 默认启用压缩传输。连接不稳定时使用 `python flash.py --port COM3 --baud 115200`；`--baud` 接受 9600～921600 的整数，实际可用速率还取决于串口设备。总耗时取决于传输、擦除、写入和校验，实际提速尚未实机测量。烧录波特率不改变固件日志的 115200 baud。

分段偏移及 Flash 参数以本次构建的 `build\auto\flasher_args.json` 为准；若其中 Flash 频率不是 `26m`，请更新本地 `sdkconfig` 并重新运行 `python build.py`，烧录脚本会拒绝旧的 40 MHz 产物。烧录完成后断开 P4 短接并复位。`full_flash.bin` 从 `0x0` 整片写入会清除 NVS 中保存的规则、红外编码及共享载波；需保留数据时使用分段命令。固件产物及最新验证见 [本地发布](../README.md#本地发布)。指定 `--port COM3 --dry-run` 不打开串口，也不核验 esptool 文件；预检通过只表示布局检查通过，设备烧录须另行连接设备执行。

## SDK 定时器构建工具

`lwip_power.cmake` 按配置生成构建目录中的 `lwip_timeouts.c`，`lwip_timers.inc` 提供网络周期暂停/恢复实现。`noise_power.cmake` 与 `expose_timers.py` 生成项目内静态库及休眠源码副本，为实际 SDK 定时器对象添加符号别名。`components\esp8266` 接入这些副本；不会修改已安装 SDK，匹配失败时停止构建。开关、回退条件和验收见 [休眠与供电](../README.md#休眠与供电) 与 [功耗验收](../README.md#功耗验收)。

## 本地额外工具

工作区另有 `flash_download_tool\flash_download_tool_3.9.11.exe`，未被 `flash.py` 使用。已有只读检查记录称其包含 esptool/ESP8266 资源，采用 PyInstaller 打包且无版本元数据或数字签名；本次未重新核验这些属性。文件名不足以确认实际版本、来源和运行行为。该额外工具未纳入 Git，不属于项目构建或自动烧录流程。

该文件大小为 26,519,970 字节，本地 SHA256 为 `193f4f4113e5f315ad19175dd33456ba632801699f5b67e52ce164f11d7a54ca`，仅用于识别本地文件，不代表来源已核验。

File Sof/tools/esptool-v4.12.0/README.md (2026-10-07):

# esptool.py

基于 Python 的开源跨平台工具，用于与 Espressif 芯片的 ROM bootloader 通信。本文件于 2026-10-05 按本项目用途整理为中文，保留上游链接、作者署名与许可；工具程序和 LICENSE 未修改。

 

## 文档与本项目用法

上游 [文档](https://docs.espressif.com/projects/esptool/) 和工具帮助提供完整说明；在线文档可能对应更新版本，本地参数以本目录 4.12.0 可执行文件的 `-h` 输出为准。本目录保存 Windows 可执行版，本项目的接线、参数、校验值及 NVS 保留方法见 [烧录工具说明](../README.md)。在 `Sof` 固件目录的 PowerShell 中可运行：

```powershell
& .\tools\esptool-v4.12.0\esptool.exe version
& .\tools\esptool-v4.12.0\esptool.exe -h
```

推荐使用项目 `flash.py` 读取构建布局，项目脚本默认 460800 baud、分段烧录并保留未覆盖的 NVS；该默认值属于项目脚本，不代表上游 esptool 默认值。先执行 `python flash.py --port COM3 --dry-run` 检查布局，不打开串口；实际偏移和参数以 `build\auto\flasher_args.json` 为准，不将其他芯片示例直接用于 ESP8266。工具不负责判断空调是否接收红外，项目脚本位于 `Sof` 固件目录，从项目根目录须先执行 `Set-Location .\Sof`。当前固件的产物与验证记录见 [本地发布](../../README.md#本地发布)。

## 贡献

参与上游开发请阅读 [贡献指南](https://docs.espressif.com/projects/esptool/en/latest/contributing.html)。

## 作者与维护

按上游说明，esptool.py 最初由 Fredrik Ahlberg（@[themadinventor](https://github.com/themadinventor/)）创建，后由 Angus Gratton（@[projectgus](https://github.com/projectgus/)）维护，并由 Espressif Systems 支持；社区成员也参与了改进。

## 许可

本文件与附带源码沿用上游的 GNU General Public License Version 2 or later。参见本目录 [LICENSE](LICENSE) 及原始 [上游 LICENSE 链接](https://github.com/espressif/esptool/blob/master/LICENSE)。

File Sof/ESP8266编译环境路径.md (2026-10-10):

# ESP8266 编译环境路径

本机工具路径见下表；当前构建的检查日期和结果见 [本地发布](README.md#本地发布)。其他机器须按实际安装位置配置，不保证相同路径可用。

| 用途 | 路径 |
| --- | --- |
| ESP8266 RTOS SDK 3.4 | `D:\APPS\Espressif\frameworks\ESP8266_RTOS_SDK` |
| Xtensa LX106 工具链目录 | `D:\APPS\Espressif\tools\xtensa-lx106-elf\esp-2020r3-49-gd5524c1-8.4.0\xtensa-lx106-elf\bin` |
| GCC 编译器 | `D:\APPS\Espressif\tools\xtensa-lx106-elf\esp-2020r3-49-gd5524c1-8.4.0\xtensa-lx106-elf\bin\xtensa-lx106-elf-gcc.exe` |
| SDK 构建脚本 | `D:\APPS\Espressif\frameworks\ESP8266_RTOS_SDK\tools\idf.py` |
| Python 环境 | `D:\APPS\Espressif\python_env\idf5.2_py3.11_env\Scripts\python.exe` |
| CMake 3.13.4 | `D:\APPS\Espressif\tools\cmake\3.13.4\bin\cmake.exe` |
| Ninja 1.9.0 | `D:\APPS\Espressif\tools\ninja\1.9.0\ninja.exe` |

本机既有记录中 Xtensa GCC 为 8.4.0，ESP8266 RTOS SDK 登记为 3.4；既有工具核验结果见本地发布。Python 环境目录虽含 `idf5.2`，本项目使用的 SDK 仍为 ESP8266 RTOS SDK 3.4。

本工作区 Git 根目录为 `D:\空调温度`，固件构建入口为 `D:\空调温度\Sof`，先在 PowerShell 中切换到该目录，再运行 `python build.py`；脚本默认使用上述本机工具，`IDF_PATH` 环境变量仅覆盖 SDK 路径。CMake、Ninja、Python 在默认位置不存在时，脚本从 `PATH` 查找；Xtensa 工具链同样允许从 `PATH` 查找。`Z:` 必须空闲，脚本运行时临时映射该盘符，结束后解除映射。分段固件、`full_flash.bin`、`full_flash.hex` 和 `flasher_args.json` 均在 `build\auto\`，无需预先创建英文路径入口。规则测试使用上述 Ninja，以 `-j 12` 执行 `tests\build.ninja`。

`sdkconfig.defaults` 分别设置 ESP-12F 晶振和 Flash 频率为 26 MHz，UART0 固件日志和串口监视器为 115200 baud。项目 `flash.py` 独立使用默认烧录速率 460800 baud，连接不稳定时传入 `--baud 115200`；烧录速率不改变日志速率。构建生成的 `sdkconfig` 被 Git 忽略，实际参数以 `sdkconfig`、`build\auto\config\sdkconfig.h` 和 `build\auto\flasher_args.json` 为准。

CPU 固定为 80 MHz（按配置重新构建可回退 160 MHz），自动 light sleep 需 `CONFIG_PM_ENABLE=y`；HTTP 请求头与 URI 上限分别为 2048、1024 字节。defaults 不覆盖已有 `sdkconfig`，增量构建前须核对这些参数。`components\esp_http_server` 与 `components\esp8266` 从 `IDF_PATH` 复用 SDK 配置和实现，不能脱离 SDK 单独构建。定时器开关在构建目录生成源码及静态库副本，原 SDK 保持不变；源码或对象布局不匹配时构建报错。配置开关见 [休眠与供电](README.md#休眠与供电)。

主机测试另需 `PATH` 中可用的 GCC、Python 和 Node.js，与固件的 Xtensa 编译器及构建脚本选用的 Python 环境不同。基础主机检查使用 GCC、Python 和 Node.js；覆盖统计另使用 gcov 与本地 Python coverage，运行器已纳入 0.1J 源码；当前 0.5A 与历史发布的验证边界见本地发布。完整检查命令见 [软件检查](README.md#软件检查)，工具版本记录和最新构建结果见 [本地发布](README.md#本地发布)。

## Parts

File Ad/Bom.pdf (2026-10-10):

Designator | Comment | Footprint | Quantity
C1, C3, C10 | 10uF | 0603_C | 3
C2, C7, C11, C12 | 100nF | 0603_C | 4
C4, C6, C9 | 4.7uF | 0603_C | 3
C5 | 220nF | 0603_C | 1
C8 | 1nF | 0603_C | 1
D1 | LED1 | LED-1 | 1
P1 | typeC | USB_C_M | 1
P2 | Header 2 | CR2450 | 1
P3 | Header 4 | HDR1X4 | 1
P4 | Header 2 | HDR1X2 | 1
R1, R2, R4, R5 | NC | 0603_R | 4
R3, R6 | 5.1KΩ ±1% | 0603_R | 2
R7 | 4.7K | 0603_R | 1
R8 | 330K | 0603_R | 1
R9 | 82K | 0603_R | 1
R10 | 1K | 0603_R | 1
R11 | 9.1R | 0603_R | 1
R12, R13, R14, R15, R17, R18 | 11K | 0603_R | 6
R16 | 62R | 0603_R | 1
S1, S2 | SW-PB | 6x6-key | 2
T1 | 9014 | TO-92 | 1
U1 | TP4057 | SOT-23-6 | 1
U2 | MG6228T5-33 | SOT-23-5 | 1
U3 | ESP-12F | ESP-12F-16Pin | 1
U4 | HS0038B | HS0038B | 1
U5 | ds18b20 | TO-92 | 1

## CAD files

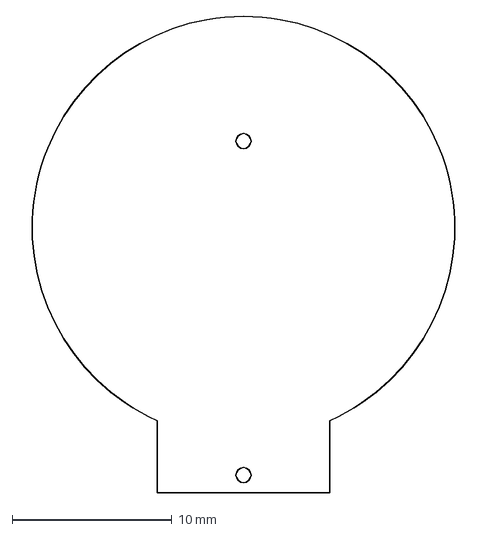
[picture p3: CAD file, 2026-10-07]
dxf-pdf/电池座.DXF
28.5 x 29.8 mm

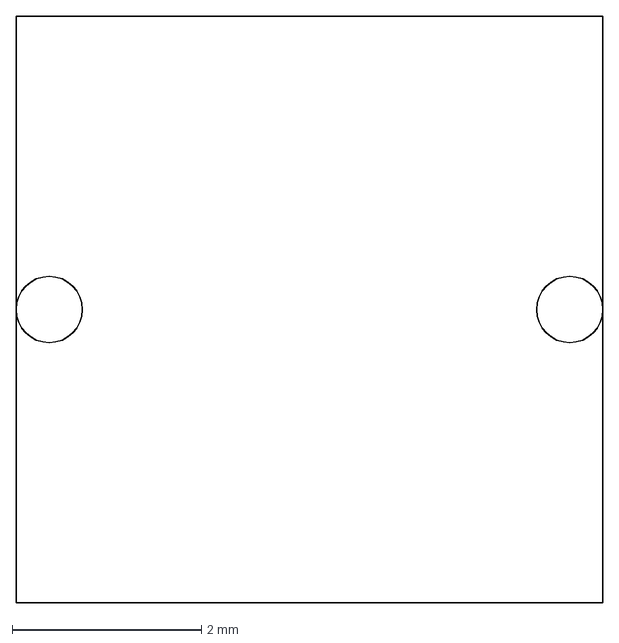
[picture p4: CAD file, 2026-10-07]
dxf-pdf/6x6-key.DXF
6.20 x 6.20 mm

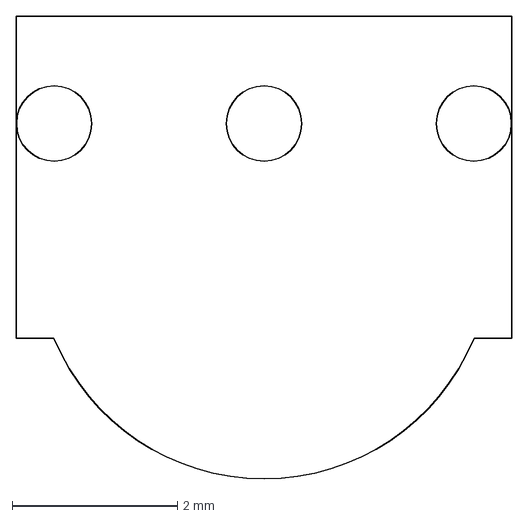
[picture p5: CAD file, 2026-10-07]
dxf-pdf/HS0038B.DXF
6.00 x 5.60 mm

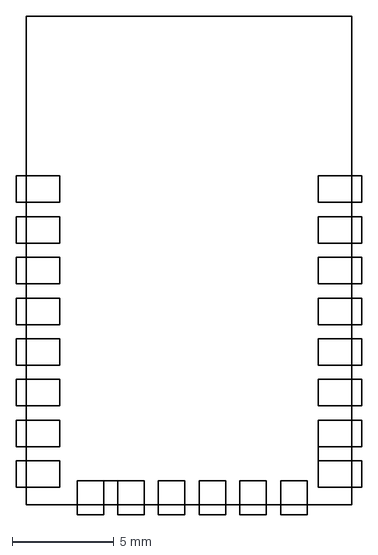
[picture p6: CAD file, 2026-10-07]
dxf-pdf/ESP-12F.DXF
17.0 x 24.5 mm

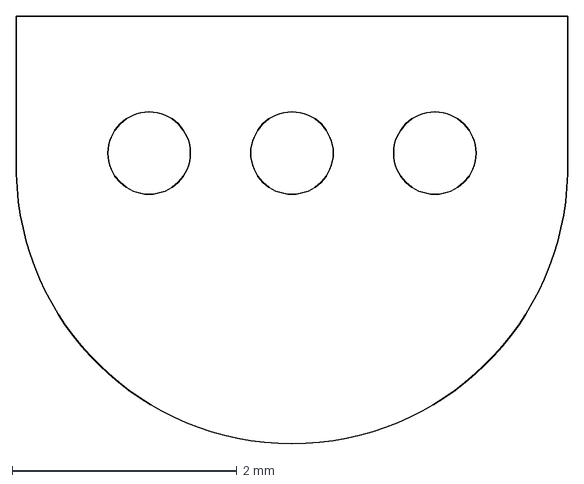
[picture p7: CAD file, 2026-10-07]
dxf-pdf/TO-92.DXF
4.90 x 3.80 mm

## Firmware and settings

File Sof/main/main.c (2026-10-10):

#include <stdlib.h>
#include <string.h>
#include "freertos/FreeRTOS.h"
#include "freertos/task.h"
#include "freertos/semphr.h"
#include "driver/gpio.h"
#include "driver/adc.h"
#include "driver/rtc.h"
#include "esp8266/gpio_struct.h"
#include "esp_wifi.h"
#include "esp_sleep.h"
#include "esp_log.h"
#include "esp_attr.h"
#include "esp_clk.h"
#include "nvs.h"
#include "nvs_flash.h"
#include "app.h"
#include "sensor.h"
#include "ir.h"
#include "portal.h"
#include "sleep_trace.h"
#include "rom/uart.h"

static const char *TAG = "thermostat";
static SemaphoreHandle_t status_lock;
static app_status_t current;
static rule_state_t states[2];
static rule_trend_t trend;
static TickType_t last_send[2];
static bool send_recorded[2];
static volatile bool s1_pending;
static volatile bool s2_pending;
static volatile uint32_t button_count[2];
static TaskHandle_t main_handle;
static volatile bool led_enabled;
static volatile bool led_learning;
static TaskHandle_t led_handle;
static bool auto_sleep;
static bool sleep_failed;
static bool adc_sleep_seen;
static bool battery_ap_active, battery_after_ap;
static TickType_t battery_off_tick;
static uint32_t battery_off_samples;
static int16_t temp_adjust10;
typedef struct { uint16_t reference_mv, base_mv; } battery_adjust_t;
static battery_adjust_t battery_adjust = {1, 1};
static int16_t base_temp10;
static uint16_t base_battery_mv;
static TickType_t temp_sample_tick, battery_sample_tick;
static bool battery_sample_ap;

#ifdef CONFIG_APP_QUIET_UART
static int quiet_log(int ch)
{
    return ch;
}
#endif

static esp_err_t init_idle_pins(void)
{
    gpio_config_t cfg = {
        .mode = GPIO_MODE_INPUT, .pull_up_en = GPIO_PULLUP_DISABLE,
        .pull_down_en = GPIO_PULLDOWN_DISABLE, .intr_type = GPIO_INTR_DISABLE
    };
#ifdef CONFIG_APP_IDLE_BOOT_PINS
    cfg.pin_bit_mask = (1ULL << GPIO_NUM_0) | (1ULL << GPIO_NUM_15);
    esp_err_t err = gpio_config(&cfg);
    if (err != ESP_OK) return err;
#endif
#ifdef CONFIG_APP_QUIET_UART
    ESP_LOGI(TAG, "power measurement: runtime logs off; GPIO1 input");
    esp_log_level_set("*", ESP_LOG_NONE);
    esp_log_set_putchar(quiet_log);
    uart_tx_wait_idle(CONFIG_ESP_CONSOLE_UART_NUM);
    cfg.pin_bit_mask = 1ULL << GPIO_NUM_1;
    return gpio_config(&cfg);
#else
    (void)cfg;
    return ESP_OK;
#endif
}

/* 限制单次等待，兼容 80/160 MHz 下的 SDK 32 位休眠时钟补偿。 */
#define SLEEP_WAIT_MS (UINT32_MAX / (CONFIG_ESP8266_DEFAULT_CPU_FREQ_MHZ * 1000U) - 1000U)
/* boot/sleep 使用同一 3994 mV 标尺，随后统一应用网页人工校准比例。 */
#define BATTERY_CAL_MV 3994U
/* 2026-10-10：boot ADC746、稳定参考 3795 mV，扣除网页比例 3794/3790。 */
#define BATTERY_BOOT_ADC 786U
/* 2026-10-10 AP 同步对照：adc=702，电池端实测 3595 mV。 */
#define BATTERY_AP_CAL_MV 3595U
#define BATTERY_AP_ADC_X2 1404U
/* 2026-10-10：11 次 ADC 均值 811.09、实测 3795 mV，扣除网页比例 3794/3790。 */
#define BATTERY_SLEEP_ADC_X2 1709U

static esp_err_t check_cpu_freq(void)
{
    unsigned expected = CONFIG_ESP8266_DEFAULT_CPU_FREQ_MHZ;
    unsigned hardware = rtc_clk_cpu_freq_get() == RTC_CPU_FREQ_80M ? 80U : 160U;
    unsigned software = esp_clk_cpu_freq();
    if (hardware != expected || software != expected * 1000000U) {
        ESP_LOGE(TAG, "CPU frequency mismatch: expected=%u MHz hardware=%u MHz software=%u Hz",
                 expected, hardware, software);
        return ESP_ERR_INVALID_STATE;
    }
    ESP_LOGI(TAG, "CPU frequency verified: %u MHz", expected);
    return ESP_OK;
}

/* 休眠配置失败后尝试禁用并锁定降级状态；若无法退出已开启的休眠则终止。 */
static void set_auto_sleep(bool enabled)
{
    if (sleep_failed || auto_sleep == enabled) return;
    esp_pm_config_esp8266_t cfg = { .light_sleep_enable = enabled };
    esp_err_t err = esp_pm_configure(&cfg);
    if (err != ESP_OK) {
        ESP_LOGE(TAG, "automatic sleep configuration failed: %s", esp_err_to_name(err));
        cfg.light_sleep_enable = false;
        esp_err_t restore = esp_pm_configure(&cfg);
        if (restore != ESP_OK) {
            ESP_LOGE(TAG, "could not disable automatic sleep: %s", esp_err_to_name(restore));
            if (auto_sleep) abort();
        }
        auto_sleep = false;
        sleep_failed = true;
        ESP_LOGW(TAG, "automatic sleep disabled; temperature control continues");
        return;
    }
    auto_sleep = enabled;
}

static void set_led_enabled(bool enabled)
{
    if (led_enabled == enabled) return;
    portENTER_CRITICAL();
    led_enabled = enabled;
    if (!enabled && !led_learning) ESP_ERROR_CHECK(gpio_set_level(GPIO_NUM_2, 1));
    portEXIT_CRITICAL();
    if (led_handle) xTaskNotifyGive(led_handle);
}

void app_set_learning(bool active)
{
    portENTER_CRITICAL();
    led_learning = active;
    portEXIT_CRITICAL();
    if (led_handle) xTaskNotifyGive(led_handle);
}

static void IRAM_ATTR button_isr(void *arg)
{
    int pin = arg ? GPIO_NUM_13 : GPIO_NUM_12;
    button_count[arg ? 1 : 0]++;
    /* 按键持续低电平时先禁用中断；主任务确认释放后再启用，防止反复唤醒。 */
    GPIO.pin[pin].int_type = GPIO_INTR_DISABLE;
    GPIO.status_w1tc = 1U << pin;
    if (arg) s2_pending = true;
    else s1_pending = true;
    BaseType_t wake = pdFALSE;
    vTaskNotifyGiveFromISR(main_handle, &wake);
    if (wake) portYIELD_FROM_ISR();
}

/* 只在任务上下文输出；快照不等于硬件唤醒原因。 */
static void trace_buttons(const char *stage, TickType_t wait, uint32_t notices)
{
    portENTER_CRITICAL();
    uint32_t s1_count = button_count[0], s2_count = button_count[1];
    bool s1 = s1_pending, s2 = s2_pending;
    uint32_t levels = GPIO.in;
    unsigned intr1 = GPIO.pin[GPIO_NUM_12].int_type;
    unsigned intr2 = GPIO.pin[GPIO_NUM_13].int_type;
    unsigned wake1 = GPIO.pin[GPIO_NUM_12].wakeup_enable;
    unsigned wake2 = GPIO.pin[GPIO_NUM_13].wakeup_enable;
    portEXIT_CRITICAL();
    ESP_LOGI(TAG, "button_trace: stage=%s tick=%u wait_ticks=%u notified=%u auto=%d busy=%d levels=%u/%u intr=%u/%u wake=%u/%u isr=%u/%u pending=%d/%d",
             stage, (unsigned)xTaskGetTickCount(), (unsigned)wait, (unsigned)notices,
             auto_sleep, ir_is_busy(), (unsigned)((levels >> 12) & 1),
             (unsigned)((levels >> 13) & 1), intr1, intr2, wake1, wake2,
             (unsigned)s1_count, (unsigned)s2_count, s1, s2);
}

static void led_task(void *arg)
{
    (void)arg;
    gpio_config_t cfg = {
        .pin_bit_mask = 1ULL << GPIO_NUM_2,
        .mode = GPIO_MODE_OUTPUT,
        .pull_up_en = GPIO_PULLUP_ENABLE,
        .pull_down_en = GPIO_PULLDOWN_DISABLE,
        .intr_type = GPIO_INTR_DISABLE
    };
    esp_err_t err = gpio_config(&cfg);
    if (err != ESP_OK) {
        ESP_LOGE(TAG, "led gpio_config failed: %s", esp_err_to_name(err));
        vTaskDelete(NULL);
        return;
    }
    while (true) {
        if (led_learning) {
            portENTER_CRITICAL();
            if (led_learning) ESP_ERROR_CHECK(gpio_set_level(GPIO_NUM_2, 0));
            portEXIT_CRITICAL();
            ulTaskNotifyTake(pdTRUE, portMAX_DELAY);
        } else if (led_enabled) {
            portENTER_CRITICAL();
            if (led_enabled || led_learning) ESP_ERROR_CHECK(gpio_set_level(GPIO_NUM_2, 0));
            portEXIT_CRITICAL();
            ulTaskNotifyTake(pdTRUE, pdMS_TO_TICKS(500));
            portENTER_CRITICAL();
            if (!led_learning) ESP_ERROR_CHECK(gpio_set_level(GPIO_NUM_2, 1));
            portEXIT_CRITICAL();
            if (led_enabled && !led_learning) ulTaskNotifyTake(pdTRUE, pdMS_TO_TICKS(500));
        } else {
            portENTER_CRITICAL();
            if (!led_learning && !led_enabled) ESP_ERROR_CHECK(gpio_set_level(GPIO_NUM_2, 1));
            portEXIT_CRITICAL();
            ulTaskNotifyTake(pdTRUE, portMAX_DELAY);
        }
    }
}

/* 规则默认禁用；允许 NVS 尚无配置，但已有配置损坏时返回错误。 */
static esp_err_t load_rules(void)
{
    current.rules[0] = (rule_cfg_t){ .threshold10 = 220, .rising = 0, .enabled = 0 };
    current.rules[1] = (rule_cfg_t){ .threshold10 = 260, .rising = 1, .enabled = 0 };
    nvs_handle handle;
    esp_err_t err = nvs_open("ac", NVS_READONLY, &handle);
    if (err == ESP_ERR_NVS_NOT_FOUND) return ESP_OK;
    if (err != ESP_OK) return err;
    for (int i = 0; i < 2; i++) {
        size_t size = sizeof(rule_cfg_t);
        err = nvs_get_blob(handle, i == 0 ? "rule0" : "rule1", &current.rules[i], &size);
        if (err == ESP_ERR_NVS_NOT_FOUND) continue;
        if (err != ESP_OK || size != sizeof(rule_cfg_t) || !rule_valid(&current.rules[i])) {
            ESP_LOGE(TAG, "invalid stored rule %d: %s", i + 1, esp_err_to_name(err));
            nvs_close(handle);
            return err == ESP_OK ? ESP_ERR_INVALID_STATE : err;
        }
    }
    nvs_close(handle);
    return ESP_OK;
}

void app_get_status(app_status_t *status)
{
    xSemaphoreTake(status_lock, portMAX_DELAY);
    *status = current;
    xSemaphoreGive(status_lock);
}

static bool battery_adjust_valid(const battery_adjust_t *value)
{
    return value->reference_mv >= 2500 && value->reference_mv <= 4500 &&
           value->base_mv && value->reference_mv * 2U >= value->base_mv &&
           value->reference_mv * 2U <= value->base_mv * 3U;
}

static uint16_t adjusted_battery(unsigned base)
{
    return ((uint32_t)base * battery_adjust.reference_mv + battery_adjust.base_mv / 2U) /
           battery_adjust.base_mv;
}

static esp_err_t load_calibration(void)
{
    int16_t offset = 0;
    battery_adjust_t voltage = {1, 1};
    nvs_handle handle;
    esp_err_t err = nvs_open("ac", NVS_READONLY, &handle);
    if (err == ESP_ERR_NVS_NOT_FOUND) {
        temp_adjust10 = offset;
        battery_adjust = voltage;
        return ESP_OK;
    }
    if (err != ESP_OK) return err;
    size_t size = sizeof(offset);
    err = nvs_get_blob(handle, "temp_adj", &offset, &size);
    if (err == ESP_ERR_NVS_NOT_FOUND) { offset = 0; err = ESP_OK; }
    else if (err == ESP_OK && (size != sizeof(offset) || offset < -50 || offset > 50))
        err = ESP_ERR_INVALID_STATE;
    if (err == ESP_OK) {
        size = sizeof(voltage);
        err = nvs_get_blob(handle, "bat_adj", &voltage, &size);
        if (err == ESP_ERR_NVS_NOT_FOUND) { voltage = (battery_adjust_t){1, 1}; err = ESP_OK; }
        else if (err == ESP_OK && (size != sizeof(voltage) || !battery_adjust_valid(&voltage)))
            err = ESP_ERR_INVALID_STATE;
    }
    nvs_close(handle);
    if (err != ESP_OK) {
        ESP_LOGE(TAG, "calibration load failed: %s", esp_err_to_name(err));
        return err;
    }
    temp_adjust10 = offset;
    battery_adjust = voltage;
    ESP_LOGI(TAG, "calibration loaded: offset10=%d voltage=%u/%u",
             offset, (unsigned)voltage.reference_mv, (unsigned)voltage.base_mv);
    return ESP_OK;
}

esp_err_t app_calibrate(bool battery, int reference, bool *storage_failed)
{
    if (!storage_failed) return ESP_ERR_INVALID_ARG;
    *storage_failed = false;
    if (battery ? (reference < 2500 || reference > 4500) :
                  (reference < -100 || reference > 500)) return ESP_ERR_INVALID_ARG;
    xSemaphoreTake(status_lock, portMAX_DELAY);
    TickType_t age = xTaskGetTickCount() - (battery ? battery_sample_tick : temp_sample_tick);
    bool valid = battery ? current.battery_valid && battery_sample_ap && base_battery_mv :
                           current.temp_valid;
    if (!portal_is_on() || !valid || age > pdMS_TO_TICKS(5000)) {
        xSemaphoreGive(status_lock);
        return ESP_ERR_INVALID_STATE;
    }
    int offset = reference - base_temp10;
    battery_adjust_t voltage = {(uint16_t)reference, base_battery_mv};
    if (battery ? !battery_adjust_valid(&voltage) : (offset < -50 || offset > 50)) {
        xSemaphoreGive(status_lock);
        return ESP_ERR_INVALID_ARG;
    }
    nvs_handle handle;
    esp_err_t err = nvs_open("ac", NVS_READWRITE, &handle);
    if (err == ESP_OK) {
        int16_t stored_offset = offset;
        err = nvs_set_blob(handle, battery ? "bat_adj" : "temp_adj",
                           battery ? (const void *)&voltage : (const void *)&stored_offset,
                           battery ? sizeof(voltage) : sizeof(stored_offset));
        if (err == ESP_OK) err = nvs_commit(handle);
        nvs_close(handle);
    }
    *storage_failed = err != ESP_OK;
    if (err == ESP_OK) {
        if (battery) {
            battery_adjust = voltage;
            current.battery_mv = adjusted_battery(base_battery_mv);
        } else {
            temp_adjust10 = offset;
            current.temp10 = base_temp10 + temp_adjust10;
            memset(states, 0, sizeof(states));
            rule_trend_reset(&trend);
        }
    }
    xSemaphoreGive(status_lock);
    if (err != ESP_OK) ESP_LOGE(TAG, "calibration save failed: %s", esp_err_to_name(err));
    else if (battery) ESP_LOGI(TAG, "battery calibration saved: reference_mv=%u base_mv=%u",
                              (unsigned)voltage.reference_mv, (unsigned)voltage.base_mv);
    else ESP_LOGI(TAG, "temperature calibration saved: offset10=%d", offset);
    return err;
}

esp_err_t app_save_rule(int slot, const rule_cfg_t *rule)
{
    if (slot < 0 || slot > 1 || !rule_valid(rule)) return ESP_ERR_INVALID_ARG;
    nvs_handle handle;
    esp_err_t err = nvs_open("ac", NVS_READWRITE, &handle);
    if (err != ESP_OK) return err;
    err = nvs_set_blob(handle, slot == 0 ? "rule0" : "rule1", rule, sizeof(*rule));
    if (err == ESP_OK) err = nvs_commit(handle);
    nvs_close(handle);
    if (err != ESP_OK) {
        ESP_LOGE(TAG, "rule %d save failed: %s", slot + 1, esp_err_to_name(err));
        return err;
    }
    xSemaphoreTake(status_lock, portMAX_DELAY);
    /* 仅在持久化成功后发布新规则，避免页面状态与 NVS 不一致。 */
    current.rules[slot] = *rule;
    memset(&states[slot], 0, sizeof(states[slot]));
    xSemaphoreGive(status_lock);
    ESP_LOGI(TAG, "rule %d saved: threshold10=%d rising=%d enabled=%d",
             slot + 1, rule->threshold10, rule->rising, rule->enabled);
    return ESP_OK;
}

void app_reset_rule(int slot)
{
    if (slot < 0 || slot > 1) return;
    xSemaphoreTake(status_lock, portMAX_DELAY);
    memset(&states[slot], 0, sizeof(states[slot]));
    xSemaphoreGive(status_lock);
}

static esp_err_t init_buttons(void)
{
    gpio_config_t cfg = {
        .pin_bit_mask = (1ULL << GPIO_NUM_12) | (1ULL << GPIO_NUM_13),
        .mode = GPIO_MODE_INPUT, .pull_up_en = GPIO_PULLUP_ENABLE,
        .pull_down_en = GPIO_PULLDOWN_DISABLE, .intr_type = GPIO_INTR_DISABLE
    };
    return gpio_config(&cfg);
}

/* 等待两键都释放并经过 20 ms 确认，再恢复低电平唤醒中断。 */
static void wait_button_release(void)
{
    trace_buttons("release-enter", 0, 0);
    while (true) {
        while (gpio_get_level(GPIO_NUM_12) == 0 || gpio_get_level(GPIO_NUM_13) == 0)
            vTaskDelay(pdMS_TO_TICKS(20));
        vTaskDelay(pdMS_TO_TICKS(20));
        if (gpio_get_level(GPIO_NUM_12) && gpio_get_level(GPIO_NUM_13)) break;
    }
    ESP_ERROR_CHECK(gpio_set_intr_type(GPIO_NUM_12, GPIO_INTR_LOW_LEVEL));
    ESP_ERROR_CHECK(gpio_set_intr_type(GPIO_NUM_13, GPIO_INTR_LOW_LEVEL));
    trace_buttons("release-done", 0, 0);
}
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
void app_main(void)
{
    ESP_LOGI(TAG, "starting");
    main_handle = xTaskGetCurrentTaskHandle();
    rule_trend_reset(&trend);
    ESP_ERROR_CHECK(nvs_flash_init());
    status_lock = xSemaphoreCreateMutex();
    if (!status_lock) abort();
    ESP_ERROR_CHECK(load_rules());
    ESP_ERROR_CHECK(load_calibration());
    ESP_ERROR_CHECK(init_buttons());
    ESP_ERROR_CHECK(sensor_init());
    adc_config_t adc_cfg = { .mode = ADC_READ_TOUT_MODE, .clk_div = 8 };
    ESP_ERROR_CHECK(adc_init(&adc_cfg));
    ESP_ERROR_CHECK(ir_init());
    ESP_ERROR_CHECK(gpio_isr_handler_add(GPIO_NUM_12, button_isr, NULL));
    ESP_ERROR_CHECK(gpio_isr_handler_add(GPIO_NUM_13, button_isr, (void *)1));
    ESP_ERROR_CHECK(portal_init());
    esp_err_t wake_err = esp_sleep_enable_gpio_wakeup();
    if (wake_err == ESP_OK) wake_err = gpio_wakeup_enable(GPIO_NUM_12, GPIO_INTR_LOW_LEVEL);
    if (wake_err == ESP_OK) wake_err = gpio_wakeup_enable(GPIO_NUM_13, GPIO_INTR_LOW_LEVEL);
    if (wake_err != ESP_OK) {
        sleep_failed = true;
        ESP_LOGE(TAG, "button wakeup setup failed; automatic sleep disabled: %s",
                 esp_err_to_name(wake_err));
    }
    ESP_ERROR_CHECK(gpio_set_intr_type(GPIO_NUM_12, GPIO_INTR_LOW_LEVEL));
    ESP_ERROR_CHECK(gpio_set_intr_type(GPIO_NUM_13, GPIO_INTR_LOW_LEVEL));
    if (xTaskCreate(led_task, "led", 2048, NULL, 1, &led_handle) != pdPASS) {
        ESP_LOGE(TAG, "could not start LED task: no memory");
        abort();
    }
    for (int i = 0; i < 2; i++) {
        ESP_LOGI(TAG, "rule %d: threshold10=%d rising=%d enabled=%d ir=%s",
                 i + 1, current.rules[i].threshold10, current.rules[i].rising,
                 current.rules[i].enabled, ir_has_code(i) ? "ready" : "missing");
    }
    ESP_ERROR_CHECK(check_cpu_freq());
#ifdef CONFIG_APP_DISABLE_DHCP_CLIENT_TIMERS
    ESP_LOGI(TAG, "DHCP client cyclic timers disabled (AP-only test); DHCP server retained");
#else
    ESP_LOGI(TAG, "DHCP client cyclic timers enabled (SDK baseline)");
#endif
    ESP_LOGI(TAG, "ready; temperature interval: AP off 60 seconds, AP on 2 seconds; automatic IR: trend 120-600 seconds per rule, paused while AP on");
    ESP_ERROR_CHECK(init_idle_pins());
    TickType_t last_temp = xTaskGetTickCount();
    TickType_t last_s1 = last_temp - pdMS_TO_TICKS(200);
    TickType_t last_s2 = last_s1;
    bool sample_now = true;
    bool close_pending = false;
    if (gpio_get_level(GPIO_NUM_12) == 0) s1_pending = true;
    while (true) {
        set_auto_sleep(false);
        if (s1_pending || s2_pending) trace_buttons("button-dispatch", 0, 0);
        portENTER_CRITICAL();
        bool s1 = s1_pending;
        bool s2 = s2_pending;
        s1_pending = s2_pending = false;
        portEXIT_CRITICAL();
        TickType_t now = xTaskGetTickCount();
        if (s1 && now - last_s1 >= pdMS_TO_TICKS(200)) {
            last_s1 = now;
            if (portal_is_on()) {
                close_pending = !close_pending;
                if (ir_is_busy()) ESP_LOGI(TAG, "portal close request %s",
                                          close_pending ? "queued until IR idle" : "cancelled");
            } else {
                close_pending = false;
                esp_err_t err = portal_start();
                if (err != ESP_OK) ESP_LOGE(TAG, "portal start: %s", esp_err_to_name(err));
            }
        }
        if (s2 && now - last_s2 >= pdMS_TO_TICKS(200)) {
            last_s2 = now;
            close_pending = true;
            ESP_LOGI(TAG, "S2: low-power control requested; temperature monitoring continues");
        }
        /* 按键关闭请求延后到红外空闲，避免中断学习或发送。 */
        if (close_pending && !ir_is_busy()) {
            esp_err_t err = portal_stop();
            close_pending = err != ESP_OK;
            if (err != ESP_OK) ESP_LOGE(TAG, "portal button stop: %s", esp_err_to_name(err));
        }
        if (s1 || s2) {
            trace_buttons("button-action-done", 0, 0);
            set_led_enabled(portal_is_on());
            wait_button_release();
        }
        if (portal_is_on() && portal_idle_ms() >= portal_timeout_ms() &&
            !ir_is_busy()) {
            esp_err_t err = portal_stop();
            if (err != ESP_OK) ESP_LOGE(TAG, "portal timeout stop: %s", esp_err_to_name(err));
        }
        set_led_enabled(portal_is_on());
        bool ap_active = portal_is_on();
        if (ap_active != battery_ap_active) {
            battery_ap_active = ap_active;
            battery_off_samples = 0;
            battery_after_ap = !ap_active;
            if (!ap_active) battery_off_tick = xTaskGetTickCount();
        }
        if (portal_is_on()) rule_trend_reset(&trend);
        /* 热点开启时每 2 秒测温，关闭时每 60 秒测温并执行趋势温控。 */
        TickType_t interval = pdMS_TO_TICKS(portal_is_on() ? 2000 : 60000);
        if (sample_now || xTaskGetTickCount() - last_temp >= interval) {
            last_temp = xTaskGetTickCount();
            sample_now = false;
            update_temp();
        }
        /* 等待时间取采样期限、热点超时和单次休眠上限的最小值；按键通知可提前唤醒。 */
        TickType_t wait = pdMS_TO_TICKS(SLEEP_WAIT_MS);
        TickType_t elapsed = xTaskGetTickCount() - last_temp;
        TickType_t remaining = elapsed < interval ? interval - elapsed : 0;
        if (remaining < wait) wait = remaining;
        if (portal_is_on()) {
            uint32_t idle = portal_idle_ms();
            uint32_t timeout = portal_timeout_ms();
            TickType_t remaining = pdMS_TO_TICKS(idle < timeout ? timeout - idle : 5000);
            if (remaining < wait) wait = remaining;
            if (close_pending && wait > pdMS_TO_TICKS(100)) wait = pdMS_TO_TICKS(100);
        }
        bool allow_sleep = !portal_is_on() && !ir_is_busy();
        bool trace_wait = !portal_is_on() && wait;
        if (trace_wait) {
            trace_buttons("wait-enter", wait, 0);
#ifndef CONFIG_APP_QUIET_UART
            uart_tx_wait_idle(CONFIG_ESP_CONSOLE_UART_NUM);
#endif
        }
        set_auto_sleep(allow_sleep);
        uint32_t notices = ulTaskNotifyTake(pdTRUE, wait);
        if (auto_sleep && wait) adc_sleep_seen = true;
        if (trace_wait) {
            set_auto_sleep(false);
            trace_buttons("wait-done", wait, notices);
        }
    }
}

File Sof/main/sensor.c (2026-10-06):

#include <stdbool.h>
#include "freertos/FreeRTOS.h"
#include "driver/gpio.h"
#include "driver/soc.h"
#include "esp8266/gpio_struct.h"
#include "esp_attr.h"
#include "rom/ets_sys.h"
#include "esp_log.h"
#include "sensor.h"

#define DQ GPIO_NUM_4
#if CONFIG_ESP8266_DEFAULT_CPU_FREQ_MHZ != 80 && CONFIG_ESP8266_DEFAULT_CPU_FREQ_MHZ != 160
#error 1-Wire slot timing requires a configured 80 or 160 MHz CPU clock
#endif
#define CPU_CYCLES_PER_US CONFIG_ESP8266_DEFAULT_CPU_FREQ_MHZ
static bool power_warned;

static esp_err_t release_bus(esp_err_t err)
{
#ifdef CONFIG_APP_SENSOR_IDLE_INPUT
    esp_err_t cleanup = gpio_set_direction(DQ, GPIO_MODE_INPUT);
    if (cleanup != ESP_OK) {
        ESP_LOGE("sensor", "bus release failed: %s", esp_err_to_name(cleanup));
        if (err == ESP_OK) err = cleanup;
    }
#endif
    return err;
}

/* 调用时已屏蔽 RTOS tick 中断，避免 ccount 被 tick 重置。
 * 边沿、延时和采样全程位于 IRAM，避免依赖 Flash cache。
 */
static void IRAM_ATTR slot_wait(uint32_t start, uint32_t us)
{
    while ((uint32_t)(soc_get_ccount() - start) < us * CPU_CYCLES_PER_US) { }
}

static bool IRAM_ATTR reset_bus(void)
{
    /* 在临界区内完成复位及存在脉冲采样，避免任务切换拉长时序。 */
    portENTER_CRITICAL();
    GPIO.out_w1tc = 1U << DQ;
    uint32_t start = soc_get_ccount();
    slot_wait(start, 480);
    GPIO.out_w1ts = 1U << DQ;
    slot_wait(start, 550);
    bool present = (GPIO.in & (1U << DQ)) == 0;
    portEXIT_CRITICAL();
    ets_delay_us(410);
    return present;
}

static void IRAM_ATTR write_bit(int bit)
{
    portENTER_CRITICAL();
    GPIO.out_w1tc = 1U << DQ;
    uint32_t start = soc_get_ccount();
    slot_wait(start, bit ? 6 : 60);
    GPIO.out_w1ts = 1U << DQ;
    slot_wait(start, 70);
    portEXIT_CRITICAL();
}

static int IRAM_ATTR read_bit(void)
{
    portENTER_CRITICAL();
    GPIO.out_w1tc = 1U << DQ;
    uint32_t start = soc_get_ccount();
    slot_wait(start, 3);
    GPIO.out_w1ts = 1U << DQ;
    slot_wait(start, 13);
    int bit = (GPIO.in >> DQ) & 1U;
    slot_wait(start, 70);
    portEXIT_CRITICAL();
    return bit;
}

static void write_byte(uint8_t value)
{
    for (int i = 0; i < 8; i++) write_bit((value >> i) & 1);
}

static uint8_t read_byte(void)
{
    uint8_t value = 0;
    for (int i = 0; i < 8; i++) value |= read_bit() << i;
    return value;
}

/* DS18B20 scratchpad 使用低位优先 CRC8，反向多项式为 0x8c。 */
static uint8_t crc8(const uint8_t *data, int len)
{
    uint8_t crc = 0;
    for (int i = 0; i < len; i++) {
        uint8_t b = data[i];
        for (int j = 0; j < 8; j++) {
            uint8_t mix = (crc ^ b) & 1;
            crc >>= 1;
            if (mix) crc ^= 0x8c;
            b >>= 1;
        }
    }
    return crc;
}

static esp_err_t read_scratchpad(uint8_t data[9])
{
    if (!reset_bus()) return ESP_ERR_NOT_FOUND;
    write_byte(0xcc);
    write_byte(0xbe);
    for (int i = 0; i < 9; i++) data[i] = read_byte();
    uint8_t expected_crc = crc8(data, 8);
    if (expected_crc != data[8]) {
        ESP_LOGW("sensor", "scratchpad=%02x %02x %02x %02x %02x %02x %02x %02x %02x; expected CRC=%02x",
                 data[0], data[1], data[2], data[3], data[4],
                 data[5], data[6], data[7], data[8], expected_crc);
        return ESP_ERR_INVALID_CRC;
    }
    return ESP_OK;
}

static esp_err_t ensure_resolution(void)
{
    uint8_t data[9], verified[9];
    esp_err_t err = read_scratchpad(data);
    if (err != ESP_OK) return err;
    if ((data[4] & 0x60) == 0x60) return ESP_OK;
    unsigned resolution = 9 + ((data[4] >> 5) & 3);
    if (!reset_bus()) return ESP_ERR_NOT_FOUND;
    write_byte(0xcc);
    write_byte(0x4e);
    /* 保留 TH/TL，只修改 RAM 分辨率；不执行 Copy Scratchpad 写 EEPROM。 */
    write_byte(data[2]);
    write_byte(data[3]);
    write_byte(data[4] | 0x60);
    err = read_scratchpad(verified);
    if (err != ESP_OK) return err;
    if (verified[2] != data[2] || verified[3] != data[3] ||
        verified[4] != (uint8_t)(data[4] | 0x60)) {
        ESP_LOGE("sensor", "12-bit configuration readback failed");
        return ESP_ERR_INVALID_RESPONSE;
    }
    ESP_LOGI("sensor", "resolution corrected: %u -> 12 bits", resolution);
    return ESP_OK;
}

esp_err_t sensor_init(void)
{
    gpio_config_t cfg = {
        .pin_bit_mask = 1ULL << DQ, .mode = GPIO_MODE_OUTPUT_OD,
        .pull_up_en = GPIO_PULLUP_DISABLE, .pull_down_en = GPIO_PULLDOWN_DISABLE,
        .intr_type = GPIO_INTR_DISABLE
    };
    esp_err_t err = gpio_config(&cfg);
    if (err == ESP_OK) err = gpio_set_level(DQ, 1);
    return release_bus(err);
}

static esp_err_t start_conversion(bool *external_power)
{
    if (!external_power) return ESP_ERR_INVALID_ARG;
    *external_power = false;
    esp_err_t err = gpio_set_direction(DQ, GPIO_MODE_OUTPUT_OD);
    if (err != ESP_OK) return err;
    if (!reset_bus()) return ESP_ERR_NOT_FOUND;
    write_byte(0xcc);
    /* Read Power Supply：返回位为 1 表示外部供电，否则按寄生供电处理。 */
    write_byte(0xb4);
    bool powered = read_bit() != 0;
    if (!powered && !power_warned) {
        ESP_LOGW("sensor", "parasite power detected; conversion sleep disabled");
        power_warned = true;
    }
    err = ensure_resolution();
    if (err != ESP_OK) return err;
    if (!reset_bus()) return ESP_ERR_NOT_FOUND;
    write_byte(0xcc);
    write_byte(0x44);
    if (powered) {
        /* 外部供电时由板上 4.7 kΩ 上拉保持 DQ 高电平，转换期间可释放输出。 */
        err = gpio_set_direction(DQ, GPIO_MODE_INPUT);
        if (err != ESP_OK) return err;
    }
    *external_power = powered;
    return ESP_OK;
}

esp_err_t sensor_start(bool *external_power)
{
    if (!external_power) return ESP_ERR_INVALID_ARG;
    esp_err_t err = start_conversion(external_power);
    return err == ESP_OK ? err : release_bus(err);
}

static esp_err_t read_temp(int16_t *temp10)
{
    esp_err_t err = gpio_set_direction(DQ, GPIO_MODE_OUTPUT_OD);
    if (err != ESP_OK) return err;
    uint8_t data[9];
    err = read_scratchpad(data);
    if (err != ESP_OK) return err;
    if ((data[4] & 0x60) != 0x60) return ESP_ERR_INVALID_STATE;
    int16_t raw = (int16_t)((data[1] << 8) | data[0]);
    /* 拒绝 85 ℃上电默认值；在舍入前加偏移，按校准后的符号处理负温度。 */
    if (raw == 0x0550) return ESP_ERR_INVALID_STATE;
    int scaled = raw * 10 + CONFIG_APP_TEMP_OFFSET10 * 16;
    *temp10 = (scaled + (scaled >= 0 ? 8 : -8)) / 16;
    ESP_LOGI("sensor", "raw16=%d resolution=12 offset10=%d temperature10=%d",
             (int)raw, CONFIG_APP_TEMP_OFFSET10, (int)*temp10);
    return ESP_OK;
}

esp_err_t sensor_finish(int16_t *temp10)
{
    if (!temp10) return ESP_ERR_INVALID_ARG;
    esp_err_t err = ESP_FAIL;
    /* 只重试 CRC 错误和设备未找到；其他错误直接上报，避免掩盖故障。 */
    for (int attempt = 1; attempt <= 3; attempt++) {
        err = read_temp(temp10);
        if (err == ESP_OK || attempt == 3 ||
            (err != ESP_ERR_INVALID_CRC && err != ESP_ERR_NOT_FOUND)) break;
        ESP_LOGW("sensor", "scratchpad read attempt %d failed: %s; retrying",
                 attempt, esp_err_to_name(err));
    }
    return release_bus(err);
}

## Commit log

2026-09-27 发布本地版本 0.1A
2026-09-27 发布本地版本 0.1B
2026-09-27 发布本地版本 0.1C 并统一串口配置
2026-09-28 发布本地版本 0.1D 并更新项目文档与烧录工具
2026-09-28 发布本地版本 0.1E 并更新项目文档
2026-09-29 发布本地版本 0.1F 并更新项目文档
2026-10-05 发布本地版本 0.1G 并更新项目文档
2026-10-05 发布本地版本 0.1H 并更新项目文档
2026-10-06 更新项目文档并保存休眠诊断与温度校准改动
2026-10-06 更新项目文档并保存采温与发送间隔调整
2026-10-07 更新项目 Markdown 文档
2026-10-07 发布本地版本 0.1I 并迁移项目根目录
    [6x6-key.DXF, ESP-12F.DXF, HS0038B.DXF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]
2026-10-07 添加可复现的固件版本标识
2026-10-07 移动页面图至根目录并在 README 展示
2026-10-09 更新项目文档并明确验证与覆盖状态
2026-10-09 更新空调温控硬件原理图
    [Sheet1.SchDoc]
2026-10-09 更新文档复验结果与当前工作区产物
2026-10-09 发布 v0.1J：修复 HTTP 与热点清理并扩展回归验证
    [rules_test.c, run_coverage.py, startup_test.c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]
2026-10-09 同步用户确认的实机验证结果
2026-10-10 整理项目文档并加入实物图，保存红外与热点修复及回归测试
2026-10-10 发布 v0.1K：纳入红外与热点修复及 PCB/BOM 资料
    [Bom.xlsx, PCB_Project.PrjPcb]
2026-10-10 发布 v0.5A：保存网页校准、学习反馈与诊断更新，整理项目文档
2026-10-12 发布 v1.0A：整理全部项目文档，保存固件、驱动与回归修复
2026-10-12 弃用旧驱动与覆盖工具：统一应用和 bootloader 固定库，保留普通回归
2026-10-12 发布 v1.0B：同步活动文档与验证结果，纳入固定驱动及覆盖工具弃用更新
2026-10-12 发布 v1.0C：固定项目 SDK、纳入 DNS 故障清理并同步文档
2026-10-13 发布 v1.0D：保存固定等待采温与校准改动，同步文档及本轮验证
2026-10-13 发布 v1.0E：保存 GPIO16 学习控制、DHCP PAD 修正及硬件修改，同步文档与验证
2026-10-13 文档：记录 GPIO16 时序与当前硬件接线实机确认
2026-10-13 清理审查报告并禁止后续生成独立审查报告
2026-10-13 发布 v1.0F：保存最新样本校准修复，同步实机确认与文档
2026-10-13 更新实物图
2026-10-20 修复 HTTP 停止超时与 DS18B20 tWR 等待，同步回归测试
2026-10-20 发布 v1.0G：纳入时序修复与仓库内文档检查，同步文档
2026-10-21 低电压 3.45V 永久深睡锁存
    连续 3 次有效采样低于 3.45 V 后进入待休眠，红外空闲时 LED 快闪约 5 秒、尽力关闭热点并写入 RTC 用户内存锁存，随后 esp_deep_sleep(0)；任何复位在 app_main 最早期回睡，仅上电复位恢复。页面补充 3.45 V 自动休眠提示。test_power 新增 8 个场景，check_page 增加文案断言。
2026-10-21 发布 v1.0H：纳入低电压深睡锁存，同步 7 份文档与功耗标准
    版本 v1.0H；7 份既有 Markdown 更新版本、Release 链接、低电压锁存说明与当前功耗标准（深睡 301μA、常态 L 休眠 500μA，200μA 降为历史记录），未新增 Markdown。
2026-10-25 低电压永久深睡阈值 3450mV 改为 3600mV，页面告警 3500mV 改为 3700mV
    BATTERY_SLEEP_THRESHOLD_MV 与页面低电量判断同步调整；锁存流程与恢复条件不变。test_power 两处 16 秒 AP 校准用例按新阈值注入 ADC 错误打断连续计数，check_page 边界用例改为 3700mV。
2026-10-25 压缩全部项目 Markdown，保留事实与历史记录，同步阈值与版本描述
    6 份项目 md 净减约 100 行：合并重复表述、删除发布记录重复样板；全部日期、数值、SHA256、链接、待确认项保留（12 条哈希逐一核对无损）。vendored esptool README 不动。check_docs 7 份文档+38 份源码通过；markdownlint-cli2 本机未安装。.gitattributes 补 .ps1 UTF-8 BOM+CRLF 约定。
2026-10-25 发布 v1.0I：低电压阈值 3.6V/3.7V，压缩全部项目文档
    版本 v1.0I；本轮构建与全套检查通过（功耗回归 69 项、Python 单测 25 项、规则/热点/HTTP/DHCP、页面、镜像/启动诊断、两种 dry-run、git diff --check、check_docs），失败 0、跳过 0；应用 BIN 549,936 字节。
2026-10-25 发布记录：check_docs 表述改为 Git 跟踪全集，不写死份数
2026-10-26 修复 P1：dry-run 不解析串口，httpd 收包超时短于停止上限
    - flash.py：`--dry-run` 未指定 `--port` 时用占位符 `<自动选择>`，不扫描注册表；真实烧录前才解析。新增 test_dry_run_without_port 覆盖。
    - portal.c：`config.recv_wait_timeout = 1`，使 httpd 接收阻塞上界短于 `httpd_stop` 的 2000 ms 等待上限，避免半开连接导致停止超时。test_portal 的 httpd_config_t mock 同步补字段。
2026-10-26 发布 v1.0J：同步 6 份文档与版本号
    - version.txt 升到 v1.0J，镜像内版本随之更新。
    - README.md、Sof/README.md：本版改为 1.0J，新增发布小节，记录本轮构建与检查结果；下载链接指向 v1.0J，旧版本改指 v1.0I。
    - Sof/tools/README.md：修正 dry-run 仍写“自动选择串口”的过期说明，改为不解析串口、显示占位符；全量烧录版本号同步。
    - Sof/README.md：httpd 段补 `recv_wait_timeout` 1 秒与 2 秒停止上限的关系；构建与烧录段补 dry-run 不解析串口；串口测试说明补 dry-run 用例。
    - Sof/ESP-12F硬件引脚与链路说明.md、Sof/ESP8266编译环境路径.md：版本号同步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
2026-11-10 发布 v1.0K：IR 永久停发修复（轮询忙状态）、1-Wire 时序放宽、S1 去抖加固，压缩全部项目文档
    - 修复 IR 永久停发根因：轻休眠节拍补偿不足使固定等待 750ms 提前返回，
    sensor_finish 读到 busy 未完成导致整轮 err!=OK、规则永不触发；改为启动
    转换后轮询 sensor_poll_status 直到 ready 再 sensor_finish。
    - 放宽 1-Wire 最脆弱时隙守门阈值（write_bit/read_bit/reset_bus），容忍现场 NMI
    或 Flash cache 缺失导致的采样点漂移；S1 开机检测加约 60ms 去抖（独立健壮性改进）。
    - Sof/version.txt 改为 v1.0K；同步更新 5 份项目 Markdown（版本号与轮询描述），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
